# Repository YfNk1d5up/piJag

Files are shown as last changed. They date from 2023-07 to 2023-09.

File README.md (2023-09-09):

# piJag

Audio/Video Screen Unit of Jaguar X Type X400 based on a raspberry and openAuto pro: bluetooth, CarPlay, OBD, remote start, climate module control

[github] https://github.com/YfNk1d5up/piJag

## Hardware & Software

 - This project was initially thought for Jaguar X-Type X400 (2001) but some parts will work for other cars
 - It uses :
    - [Rpi 4B 4GB RAM](https://www.raspberrypi.com/products/raspberry-pi-4-model-b/)
    - [OpenAuto Pro](https://bluewavestudio.io/shop/openauto-pro-car-head-unit-solution/)
    - [CarPiHat](https://thepihut.com/products/carpihat-car-interface-hat-for-raspberry-pi)
    - [10.1" TouchScreen](https://www.amazon.fr/gp/product/B0B4VMNB42/ref=ppx_yo_dt_b_search_asin_image?ie=UTF8&psc=1)
    - [Carlinkit](https://www.amazon.fr/gp/product/B09ZQF182F/ref=ppx_yo_dt_b_asin_title_o05_s00?ie=UTF8&psc=1)
    - [USB Sound Card](https://www.amazon.fr/gp/product/B00IRVQ0F8/ref=ppx_yo_dt_b_asin_title_o04_s00?ie=UTF8&psc=1)
    - [Rear Camera](https://www.amazon.fr/gp/product/B0BG5M8H76/ref=ppx_yo_dt_b_asin_title_o01_s01?ie=UTF8&psc=1)
    - [CVBS to USB adapter](https://www.amazon.fr/gp/product/B0BYJ2892S/ref=ppx_yo_dt_b_asin_title_o01_s00?ie=UTF8&psc=1)
    - [12V Voltage Regulator](https://www.amazon.fr/gp/product/B09Q1XXM6G/ref=ppx_yo_dt_b_asin_title_o02_s00?ie=UTF8&psc=1)
    - [Powered USB Hub](https://www.amazon.fr/gp/product/B0BDFG1WZ7/ref=ppx_yo_dt_b_asin_title_o06_s00?ie=UTF8&psc=1)
    - [ELM327 OBD USB](https://www.amazon.fr/gp/product/B07NSPLVYW/ref=ppx_yo_dt_b_asin_title_o07_s00?ie=UTF8&psc=1)
    - 12V relays, Fan, Microphone, 4Channel Amplificator, HDMI & RCA cables, Audio Splitter ...
 - A custom PCB to control the Climate Control Module with an arduino nano (Kicad & JLCPCB)

## Features

- **Phone** : CarPlay, Android Auto, bluetooth, messages and calls
- **Rear Camera** : Automatic on reverse gear or anytime manually
- **Videos** : Kodi & Youtube
- **OBD** : CAN & SCP (Ford Protocol) messages and control
- **Climate** : Climate Control Module App
- **Mobile App** : Start the car, turn on heater or climatisation from Phone

## Screenshots

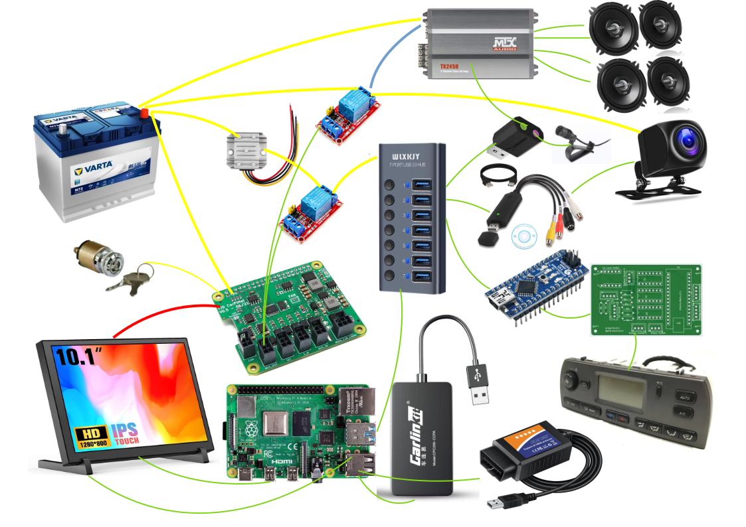
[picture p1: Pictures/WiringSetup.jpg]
Wiring Setup


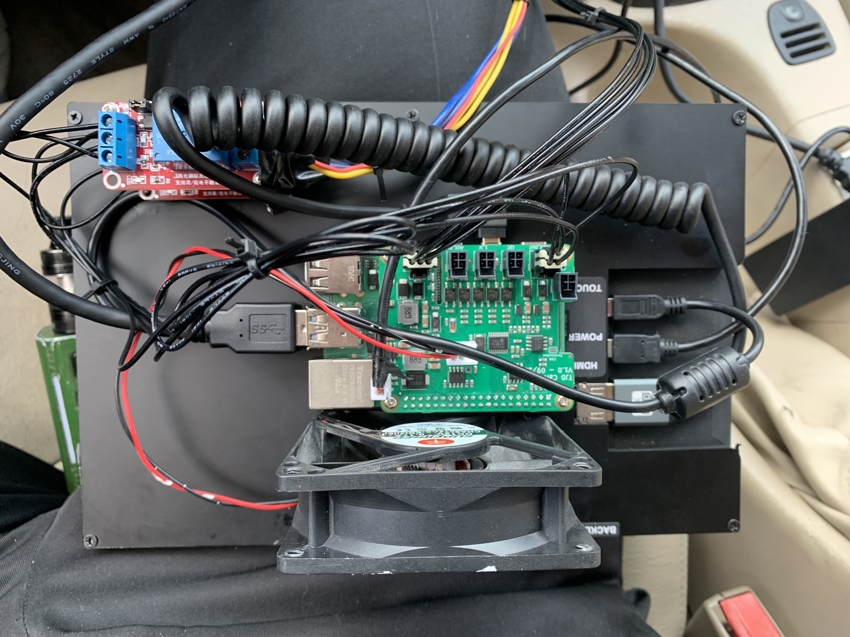
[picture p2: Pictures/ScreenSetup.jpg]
Screen Setup


Setup not clean for now (you can see the Climate Control Module annoying me for now, explaination later)...
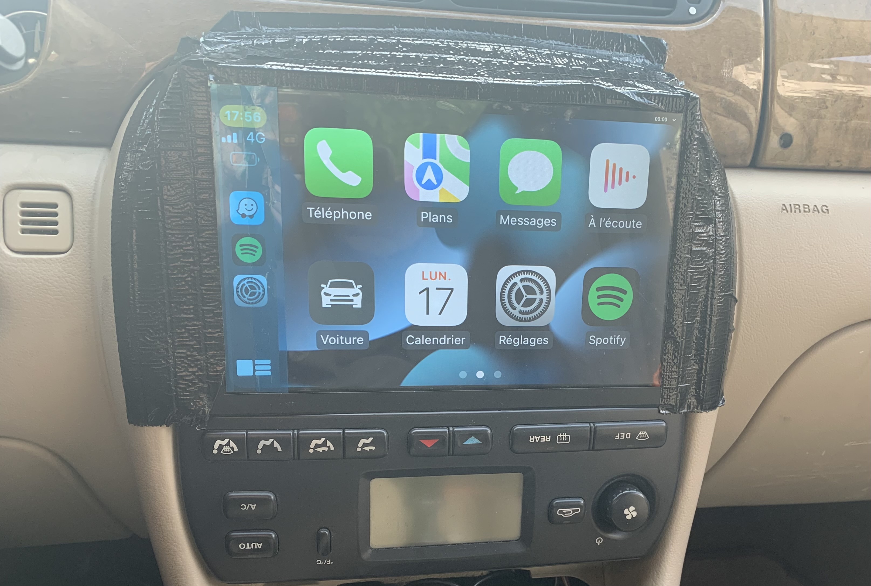
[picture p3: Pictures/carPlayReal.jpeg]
OpenAuto Pro CarPlay

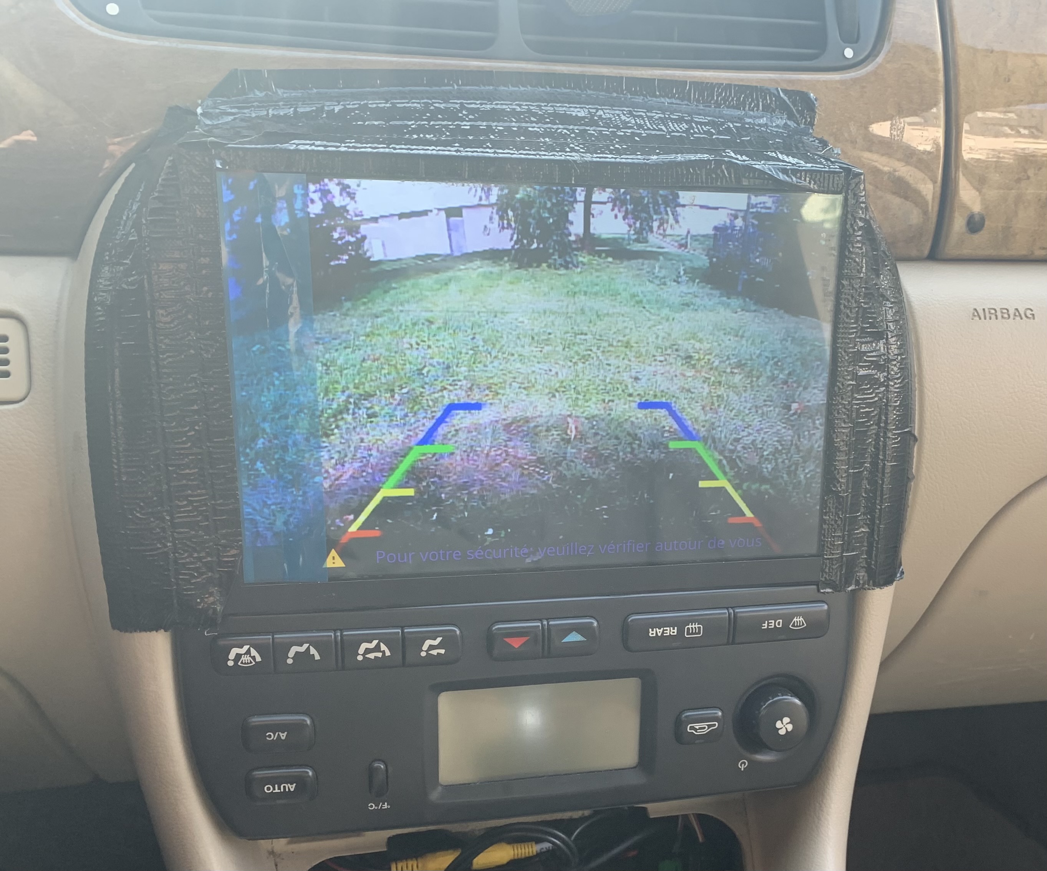
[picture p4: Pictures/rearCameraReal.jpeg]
OpenAuto Pro Rear Camera

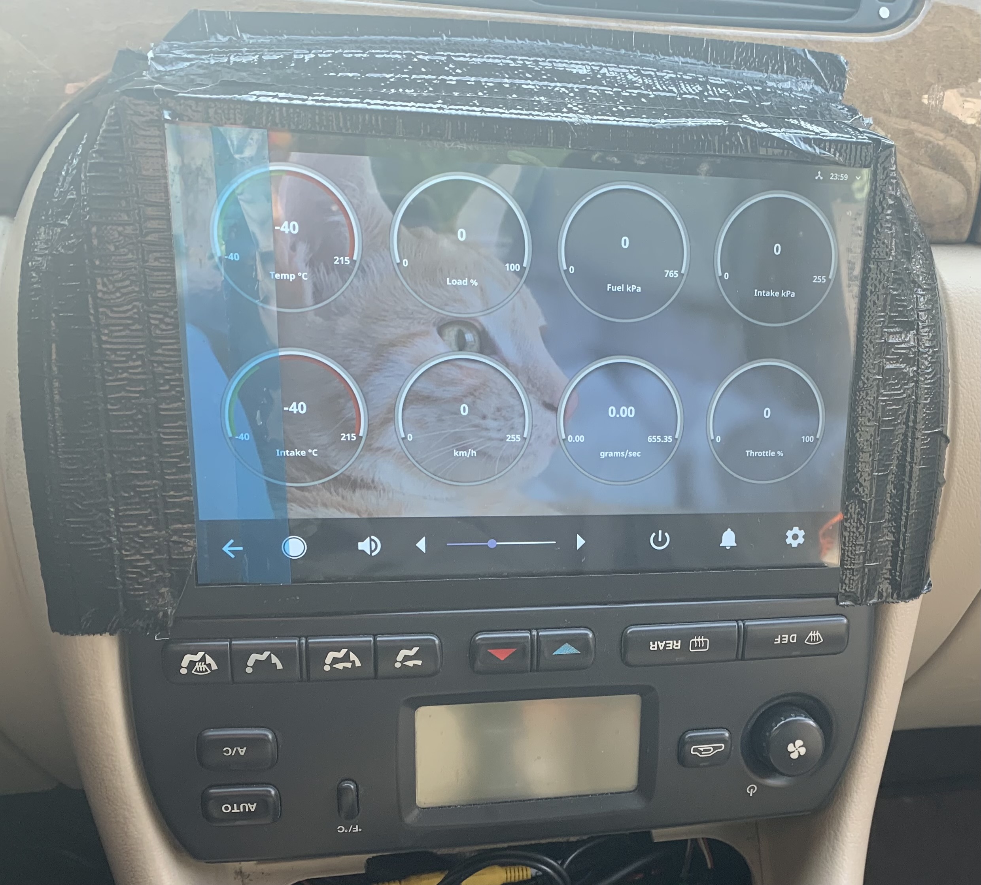
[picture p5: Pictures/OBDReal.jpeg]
OpenAuto Pro OBD

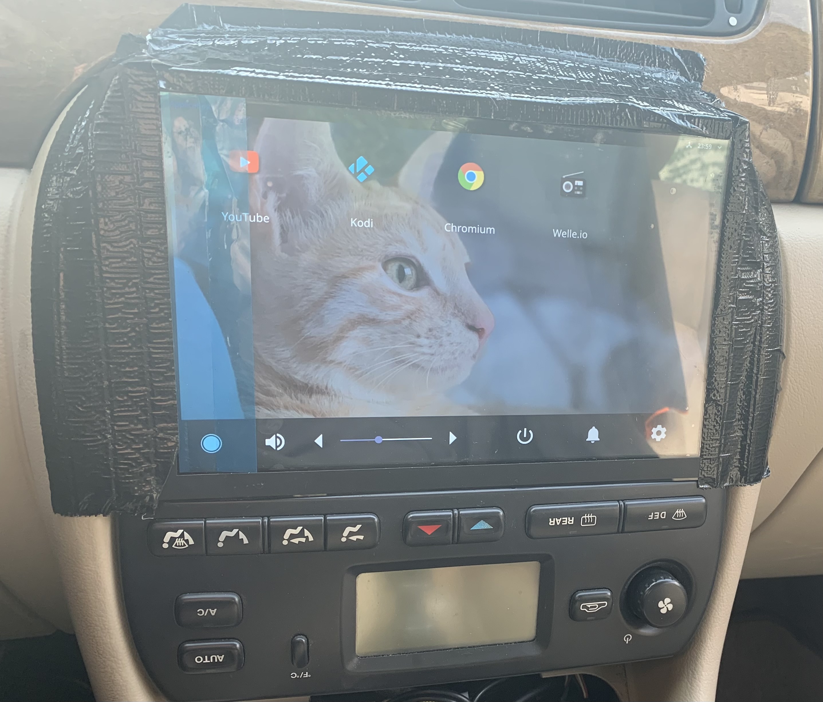
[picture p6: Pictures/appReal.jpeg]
OpenAuto Pro Apps


## Integration

### Raspberry Pi and carPiHat

The issue with installing custom hardware on a car is mainly how to power and connect them. Should I use the permanent 12V, switched 12V on key, interior lights 12V ...
The raspberry pi 4B is a 5V small computer that can draw 3A when loads are connected to it.
In this setup, a lot of usb devices are connected and I should consider this ~3A as a constant.
5V 3A, drawn from the car battery makes it impossible keeping powered on the constant battery supply.
In deed it needs to be powered off when I'm not in the car, and it needs a 12V to 5V step-down.
This is where I found [carPiHat](https://github.com/gecko242/CarPiHat) from TJD that saved me a lot of work :
- 12V - 5V buck converter to power the pi and touchscreen, with fuse and filtering.
- Safe shutdown circuitry to allow the pi to control its own power.
-  < 1mA current draw when switched off.
- Dedicated reverse, illumination and aux inputs, all opto isolated.
- 2 opto isolated general purpose inputs. (for a total of 5 inputs)
- 2 high current, high side switched 12V outputs (@1A). (for switching relays, lights ect)
- 1 independent CAN bus port.
- Real time clock to maintain system time across reboots.
- Broken out I2C bus.
- Broken out 1W for temperature sensor ect.
- 5V Power Output for display ect.

So the power aspect is done using this hat for the raspberry, connecting constant 12V, switched 12V, reverse gear input, illumination input, and GND

Then, a script makes the automation of the RPi power off 30s after turning the car off :

```python
import RPi.GPIO as GPIO # import our GPIO module
import time
from subprocess import call

GPIO.setmode(GPIO.BCM) # we are using BCM pin numbering

IGN_PIN = 12		# our 12V switched pin is BCM12
EN_POWER_PIN = 25	# our latch pin is BCM25

ILL_PIN = 13		# our 12V Illumination input pin is BCM13
REVERSE_PIN = 7	# our 12V Reverse Gear input pin is BCM7

IGN_LOW_TIME = 30 # time (s) before a shutdown is initiated after power loss

GPIO.setup(IGN_PIN, GPIO.IN) # set our 12V switched pin as an input
GPIO.setup(ILL_PIN, GPIO.IN) # same for ill and reverse 
GPIO.setup(REVERSE_PIN, GPIO.IN)

GPIO.setup(EN_POWER_PIN, GPIO.OUT, initial=GPIO.HIGH) # set our latch as an output

GPIO.output(EN_POWER_PIN, 1) # latch our power. We are now in charge of switching power off

ignLowCounter = 0

while 1:
	if GPIO.input(IGN_PIN) != 1: 				# if our 12V switched is not disabled
		time.sleep(1)							# wait a second
		ignLowCounter += 1						# increment our counter
		if ignLowCounter > IGN_LOW_TIME:		# if it has been switched off for >10s
			print("Shutting Down")
			call("sudo shutdown -h now", shell=True)	# tell the Pi to shut down
	else:
		ignLowCounter = 0 						# reset our counter, 12V switched is HIGH again

        time.sleep(0.1)  # Add a small sleep delay to reduce CPU usage
```

As said in TJD documentation in the *Opto-Isolated Inputs* section, I needed to redirect the CS1 pin to BCM24 to get ill and reverse inputs to work.

From the hat I also used the 2 outputs to control relays :
- One relay powers the **4Channels Audio Amplifier remote** and the rear camera with 12V
- The other powers the **36W USB Hub** to relieve the strain on the raspberry and charge devices.

(picture)

#### **Parts to come with carPiHat** :
- CAN integration
- I/O expander to add remote powering the car and other stuff

### TouchScreen 

Simply an HDMI and touch USB connected to the RPi, plus 5V power coming from the carPiHat

### Suffering from Hot Temperatures

During summer 2023, a lot of heat has made the setup suffer. This is where I add a 12V computer power fan to help keeping the whole setup at acceptable temperatures.

## obdSniffer

To add more control on the car, I tried to hack bus networks through the OBD2 port.

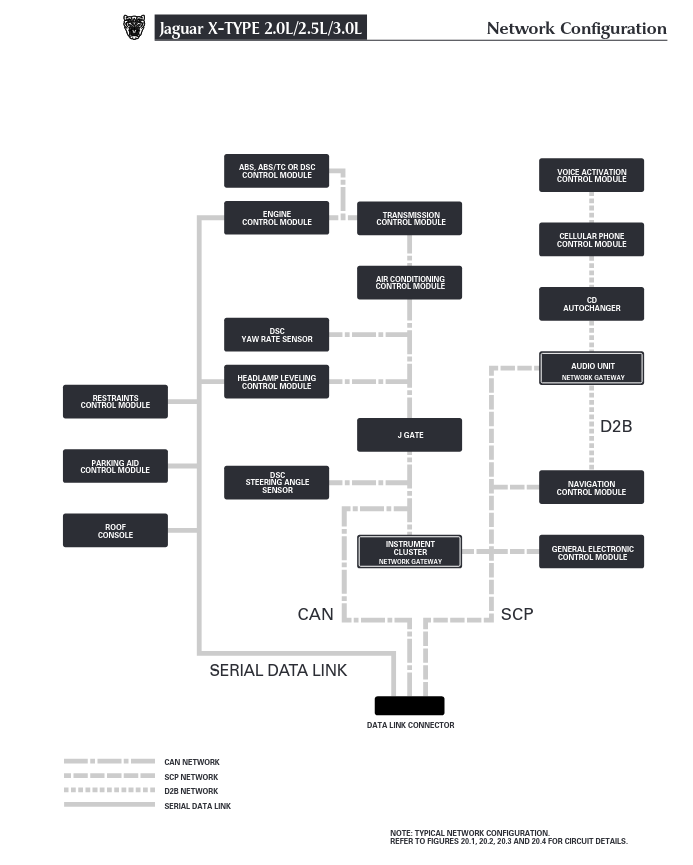
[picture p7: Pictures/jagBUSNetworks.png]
X-Type BUS Networks


### CAN Bus

Following this awesome serie from Youtube [How to hack your car ](https://youtu.be/cAAzXM5vsi0) by Adam Varga and using his python&Qt [CAN_Gui](https://github.com/adamtheone/canDrive), I copy the setup to hack into my CAN Bus.

Here are for example some data I decoded : 

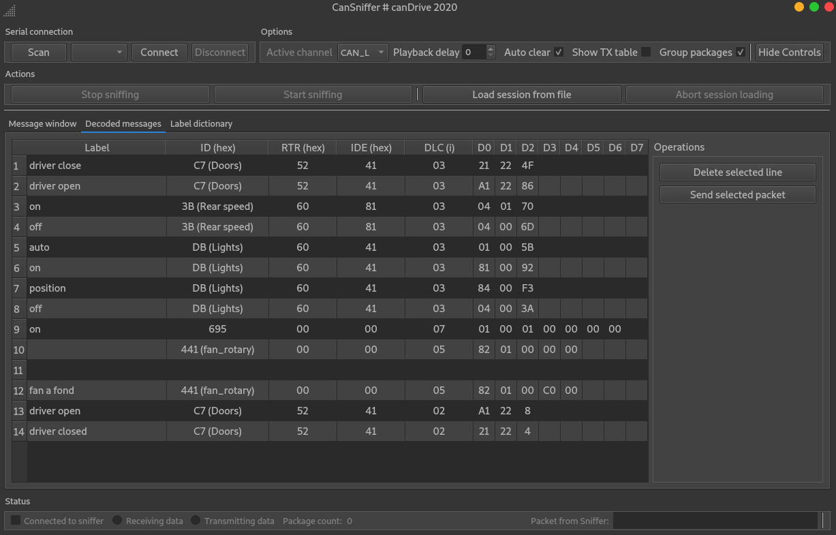
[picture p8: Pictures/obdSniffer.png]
obdSniffer GUI


### SCP Bus

As the X-Type shares its creation with the Ford Mondeo, the car uses SAEJ1850 PWM aka **Standard Corporate Protocol** or **SCP** to communicate low priority information between modules.

A modification of Adam Varga code brings me the SCP decoding using the **ELM327 OBD2 USB Reader** using **AT** commands.
Modified functions :
*serialPacketReceiverCallback*
*serialPortConnect*
file *SerialReader.py*

(You can see some SCP data on the previous screenshot)

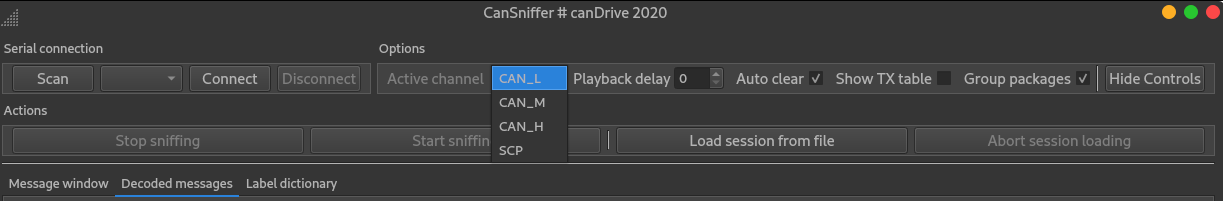
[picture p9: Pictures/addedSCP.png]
SCP Added


To achieve that, first I did some tests using AT on linux terminal

```bash
sudo screen /dev/ttyUSB0 38400
```

```bash
>atz
ELM327 v1.5

>atl1
OK

>ath1
OK

>ats1
OK

>atal
OK

>atsp1
OK

>atma

```

For AT commands explanation, SCP application case and another hardware setup, see this thread : https://www.jaguarforum.com/threads/reverse-engineering-hacking-scp-bus-to-xj-x350-x358-s-type-and-x-type.108639/

Example output :

```bash
81 29 60 02 0081 29 60 02 00 00 11
41 87 60 04 08 B1
81 7B 60 02 00 4C
81 7B 60 02 00 4C
```

See [X-Type Electrical Guide CAN/SCP](https://github.com/YfNk1d5up/piJag/blob/cf38571dc9505988becb3cf82d76548922db3a51/Docs/JagClimModule.pdf) to find more information about CAN and SCP messages

## OpenAuto Pro setup

## Climate Control Module Hack

The goal here was to remove the Control Unit that is space-consuming and overall avoid me to install the screen properly without destroying the case.
To continue adding a modern touch to my X-Type, I enjoy controlling the climate directly on the touchscreen via an app on openAuto Pro.

Firstly, I need to understand well how the existing module works.
So I bought another one to avoid getting stuck breaking it : in deed, it is connected to the CAN Bus and the car will not start if the module doesn't work or isn't connected to the bus.

By the CAN and SCP analyse done previously, I found that buttons user actions are not going through any bus on the car, plus the electrical documentation shows that the module only communicate with other modules to say an action has been performed.
FYI, the second X-Type (X404) added LIN to the buses, where climate, windows control, driver wheel buttons, etc, communicate through it.

But no chance, that is not the case for my version. So sending commands on buses to control the climate module is impossible.

That said, there is no other way than hacking electronics of the module by adding a custom Mod PCB.

The Module consists in 2 PCBs connected by a 20 wires ribbon. On the electrical documentation, only the global module connections to the rest of the car is detailed. 
Lucky for me, somebody already took a look into that module, because he wanted to change the screen to a modern one. The report is joined in [David's initial HVAC Sniffer](https://github.com/YfNk1d5up/piJag/blob/cf38571dc9505988becb3cf82d76548922db3a51/Docs/p10018_jag_hvac_sniffer.zip)

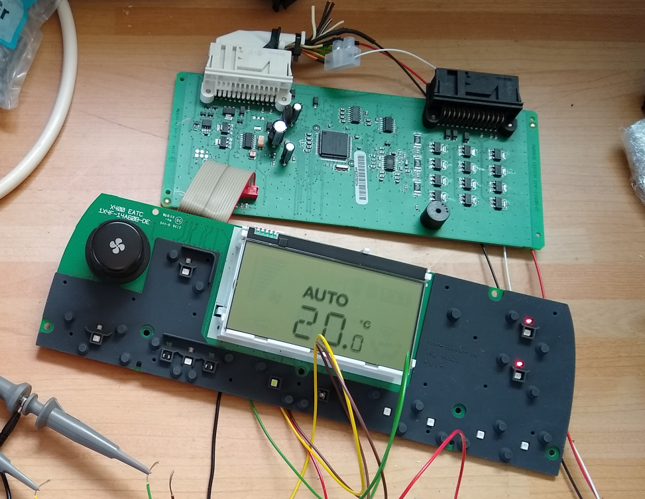
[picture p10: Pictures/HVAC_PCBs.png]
(HVAC PCBs)


The first PCB contains the MCU which does CAN communication to the rest of the vehicule, control of fans, compressor, etc : that is the one I want to keep.
The second one contains all the buttons, the LCD screen, a digital encoder, and maybe a second propietary MCU impossible to identify : I want to replace this PCB.
Doing some retro-engineering and finding the documentation of the MCU in the first PCB, here is the connection from and to that second PCB :

[Initial retro-engineering of the 2nd PCB](https://github.com/YfNk1d5up/piJag/blob/cf38571dc9505988becb3cf82d76548922db3a51/Docs/piJagClim_existing_module.pdf)

You can see here a switches matrix, using 6 wires for 12 buttons. An I2C screen connected straigth to the main MCU, a rotary encoder also directly connected to the main board.
What I used for the buttons is analog switches, that works as relays except that they are small 14 pins chips, which each entry is controlled by an Arduino digital pin. For the rotary encoder, an Arduino Nano can easily simulate the signals by using two digital pins.
Finally, using David's work about the i2c screen, I can get the information coming from the main MCU by decoding it using A4 and A5 pins on the Nano.

And so here is the mod board :
climateModBoardv0.2
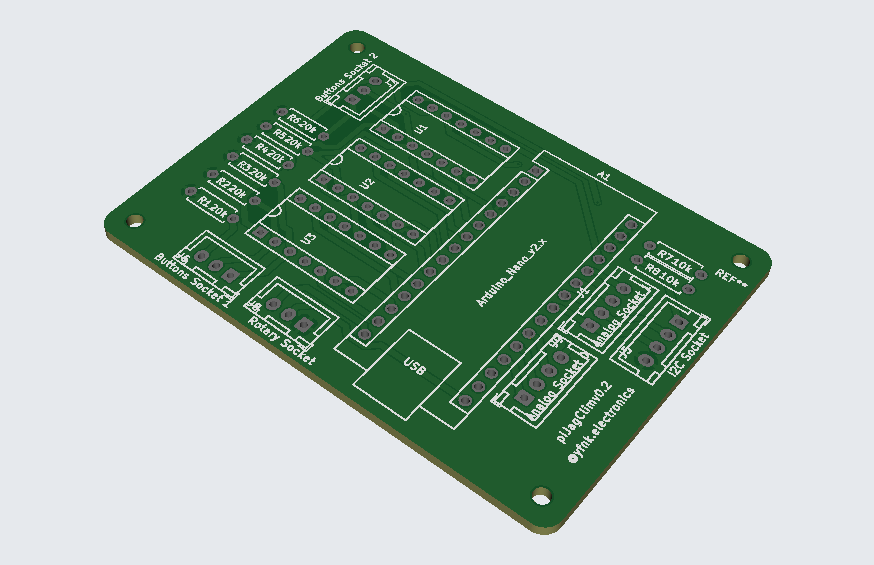
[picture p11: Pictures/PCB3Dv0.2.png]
PCB3Dv0.2


JLCPCB Manufacture :

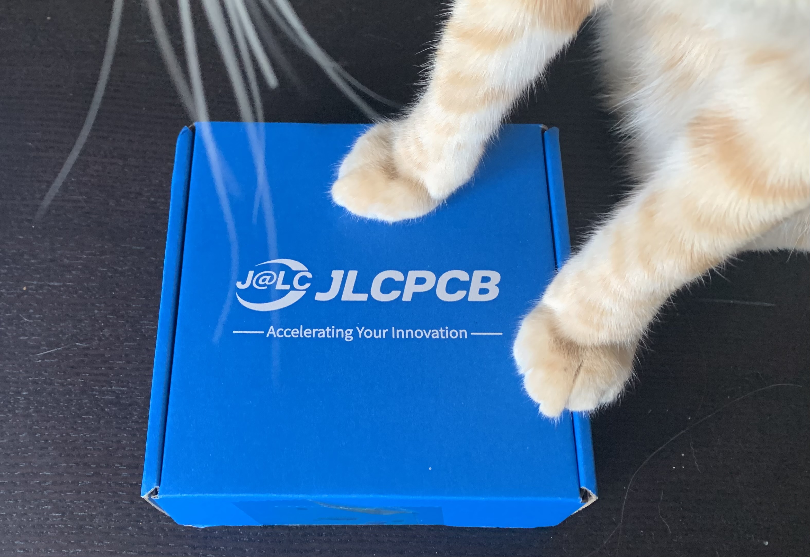
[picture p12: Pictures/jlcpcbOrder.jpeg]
JLCPCB Order

![PCB not mounted]
![PCB mounted]

To communicate with the arduino onboard, a pyQt App controls the mod, associated with an arduino code that simulates the action and transmit the i2c data.

[pyQtApp](Software/piJagClimApp)
[piJagClimI2C.ino](Hardware/piJagClim/newPCB/arduino/piJagClimI2C/piJagClimI2C.ino)

Here you can see the Qt App v0.1 :
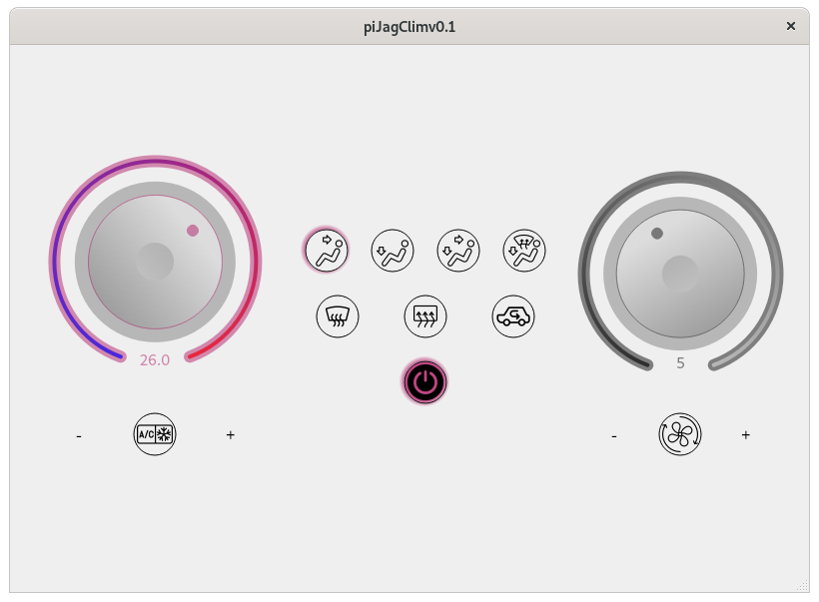
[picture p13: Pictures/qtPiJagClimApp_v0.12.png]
piJagClimAppv0.1


## Ressources

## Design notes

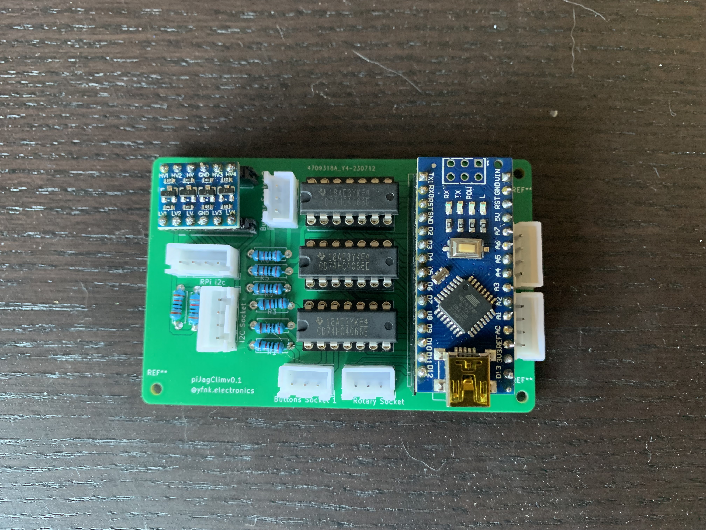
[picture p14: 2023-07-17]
Pictures/PCBmounted.jpeg

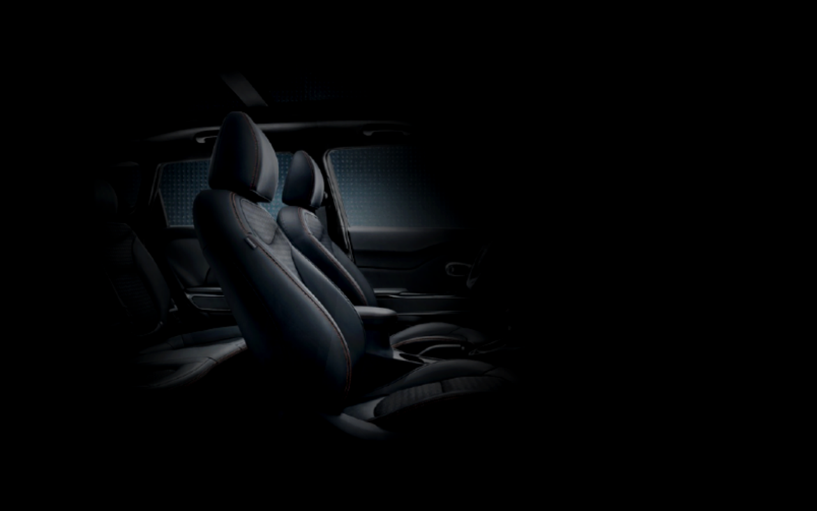
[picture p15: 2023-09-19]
Software/piJagClimApp/v0.2/pictures/background.png

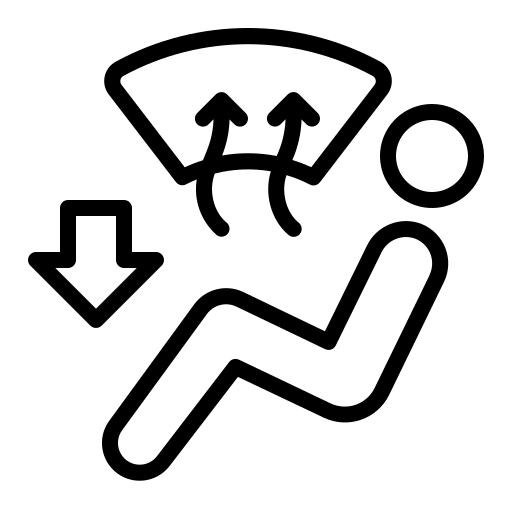
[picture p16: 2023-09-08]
Software/piJagClimApp/v0.2/pictures/feetfront.png

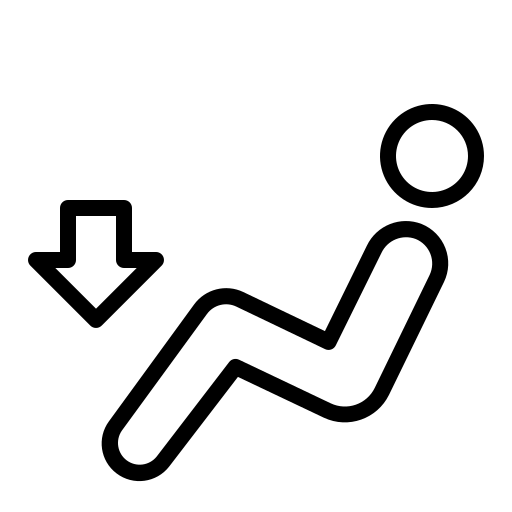
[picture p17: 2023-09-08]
Software/piJagClimApp/v0.2/pictures/feet.png

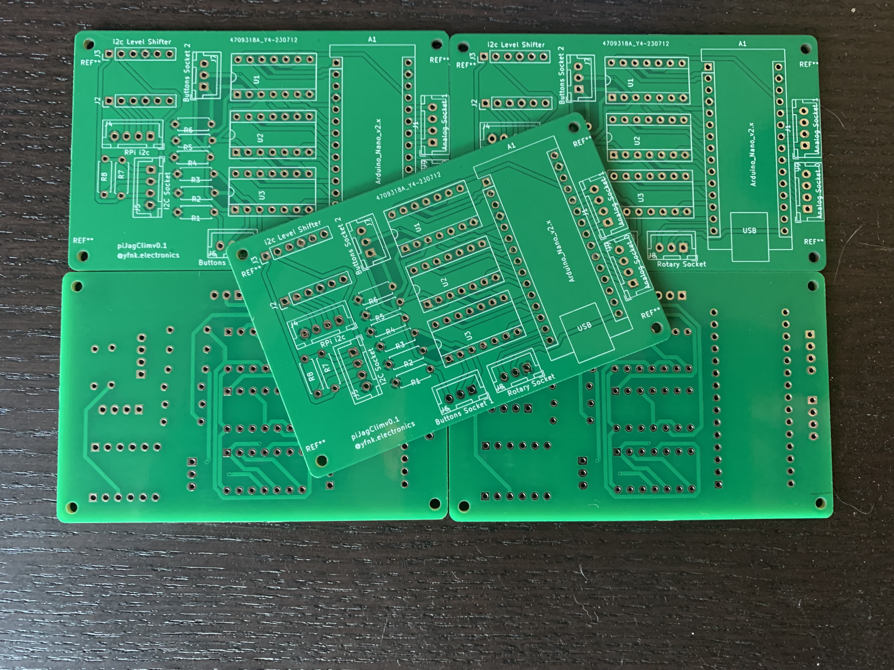
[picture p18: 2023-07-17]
Pictures/PCBnotmounted.jpeg

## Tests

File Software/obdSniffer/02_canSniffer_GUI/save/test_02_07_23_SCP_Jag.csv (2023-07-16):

600.969 | FE | 60 | 41 | 01 | 82 | 5
601.801 | 89 | 52 | 41 | 01 | 50 | 0
601.657 | 39 | 52 | 41 | 02 | 82 | 01 | B
601.833 | 93 | 60 | 41 | 03 | 06 | 7F | 01 | D
640.298 | C7 (Doors) | 52 | 41 | 02 | 21 | 26 | 3
601.609 | 33 (Handbrake) | 60 | 41 | 01 | A0 | C
601.898 | 85 | 60 | 41 | 01 | 21 | 1
602.025 | 88 (Driver Belt) | 52 | 41 | 01 | 81 | 6
236.633 | 8D (Climate) | 60 | A1 | 07 | 01 | 00 | 00 | 00 | 00 | 00 | 00 | 9
601.866 | DB (Lights) | 60 | 41 | 02 | 04 | 00 | 3
743.545 | 3B (Rear speed) | 60 | 81 | 02 | 04 | 00 | 6
744.009 | 29 | 60 | 81 | 03 | 02 | 00 | 00 | 1
743.929 | 87 | 60 | 41 | 02 | 04 | 08 | B
744.073 | 7B | 60 | 81 | 02 | 02 | 00 | 4

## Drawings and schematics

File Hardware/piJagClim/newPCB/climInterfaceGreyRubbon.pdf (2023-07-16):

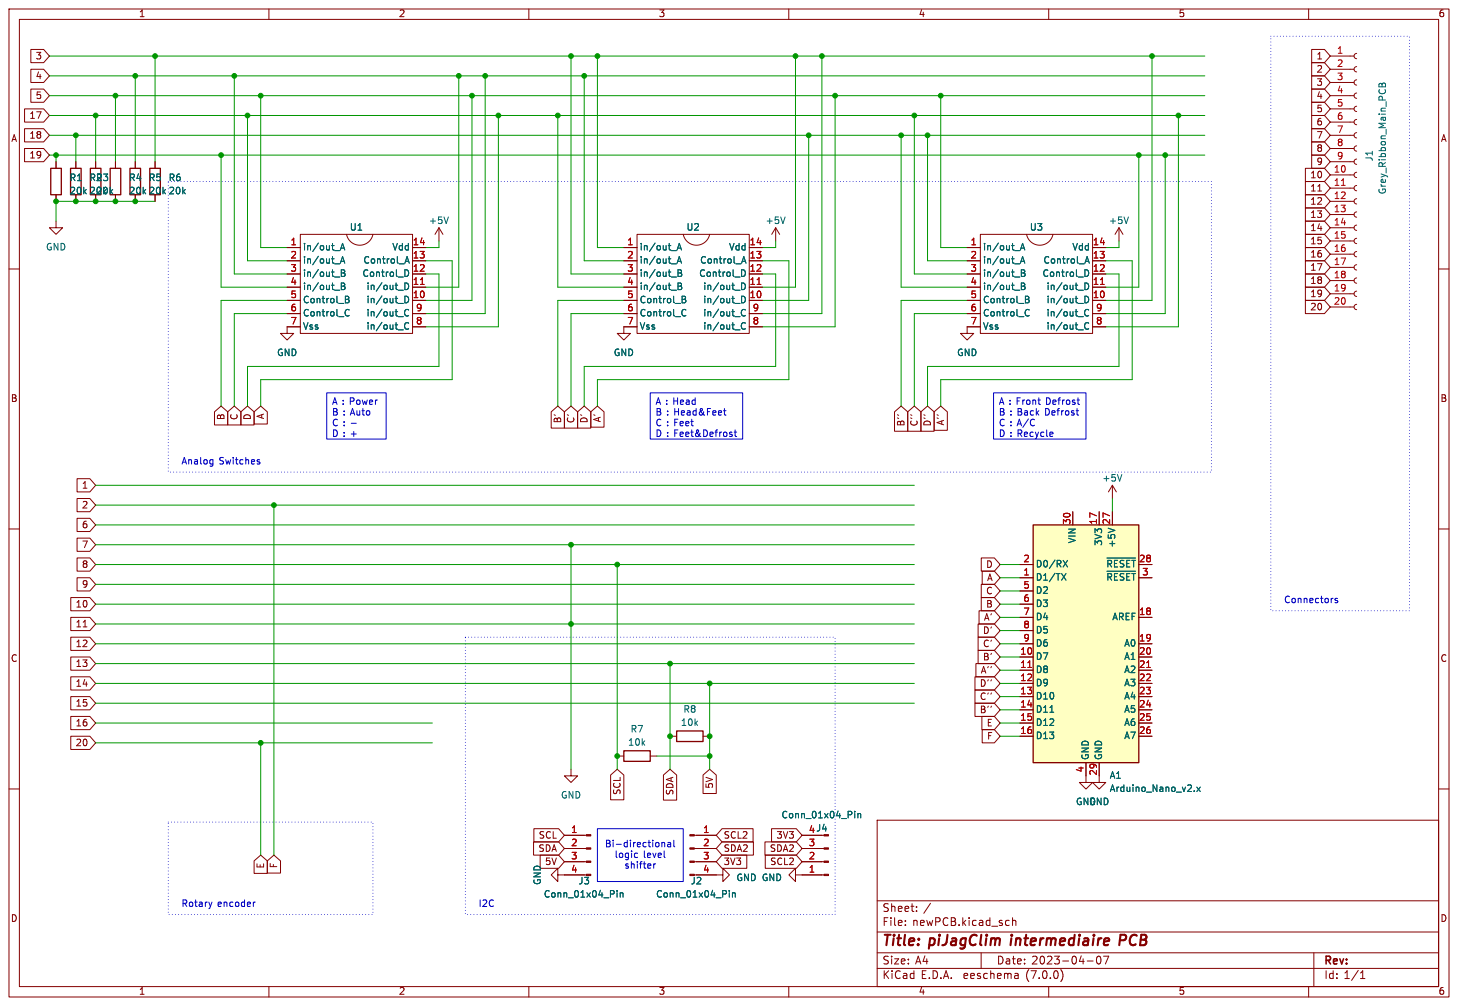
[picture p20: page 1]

File: newPCB.kicad_sch Sheet: /
Id: 1/1 Title: piJagClim intermediaire PCB

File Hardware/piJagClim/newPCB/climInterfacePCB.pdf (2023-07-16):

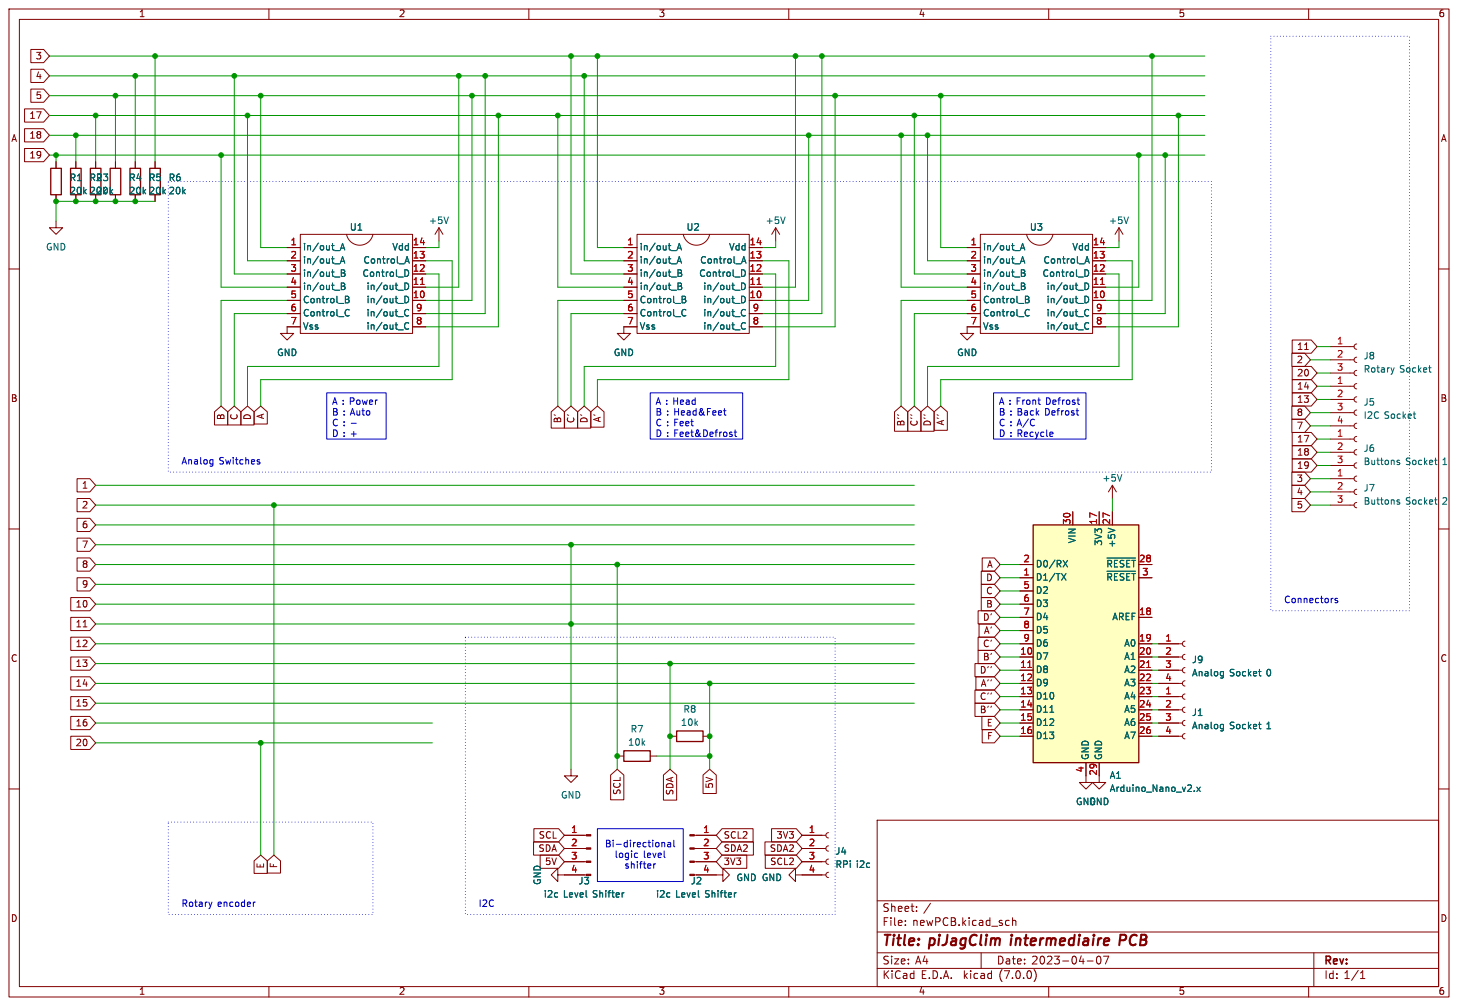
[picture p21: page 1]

File: newPCB.kicad_sch Sheet: /
Id: 1/1 Title: piJagClim intermediaire PCB

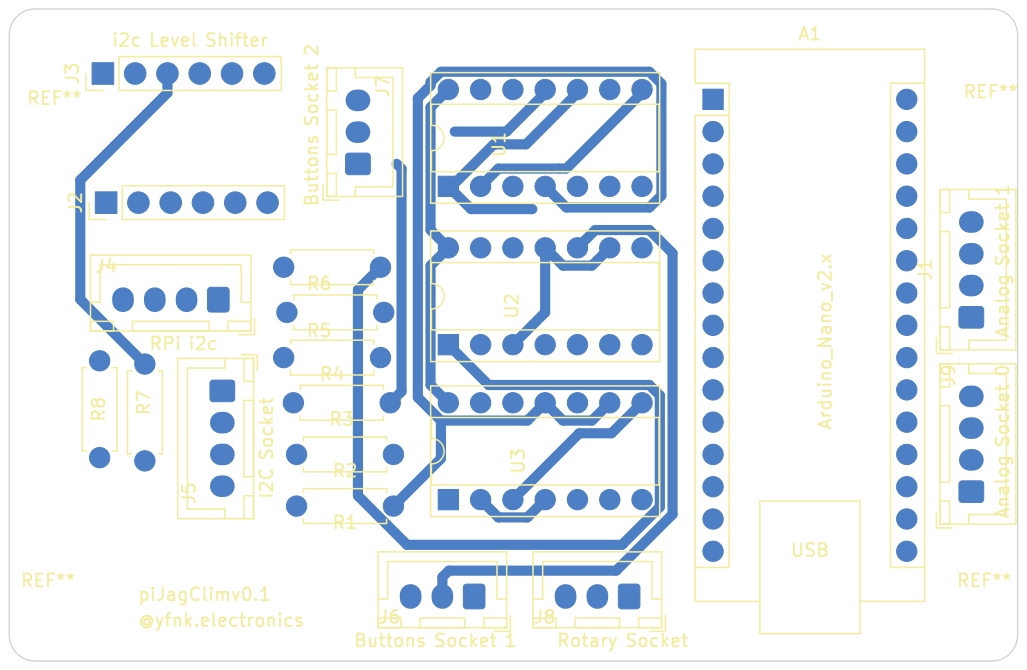
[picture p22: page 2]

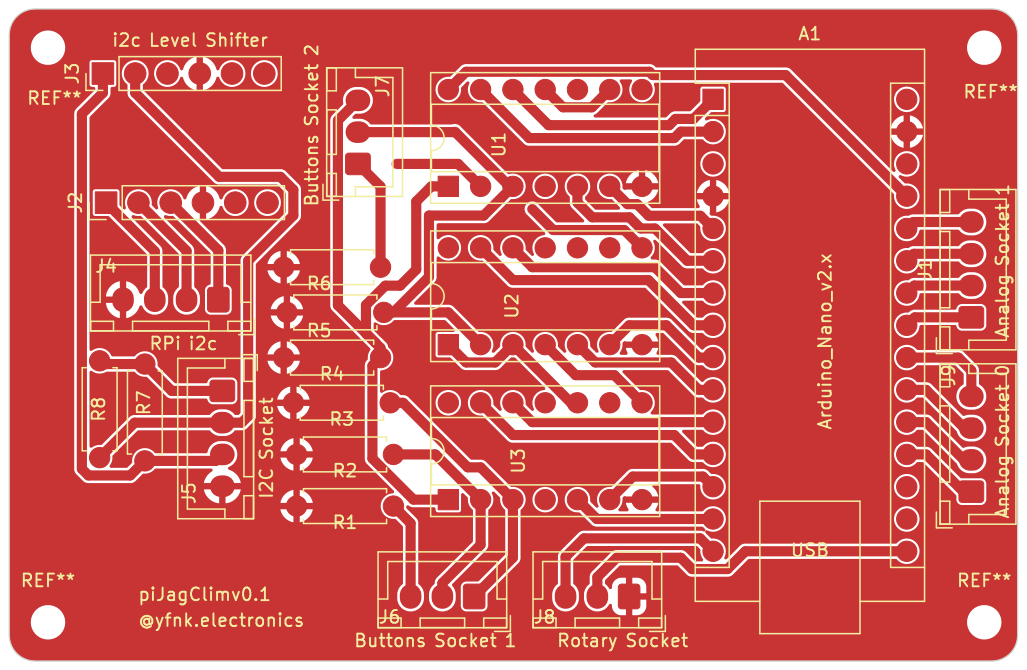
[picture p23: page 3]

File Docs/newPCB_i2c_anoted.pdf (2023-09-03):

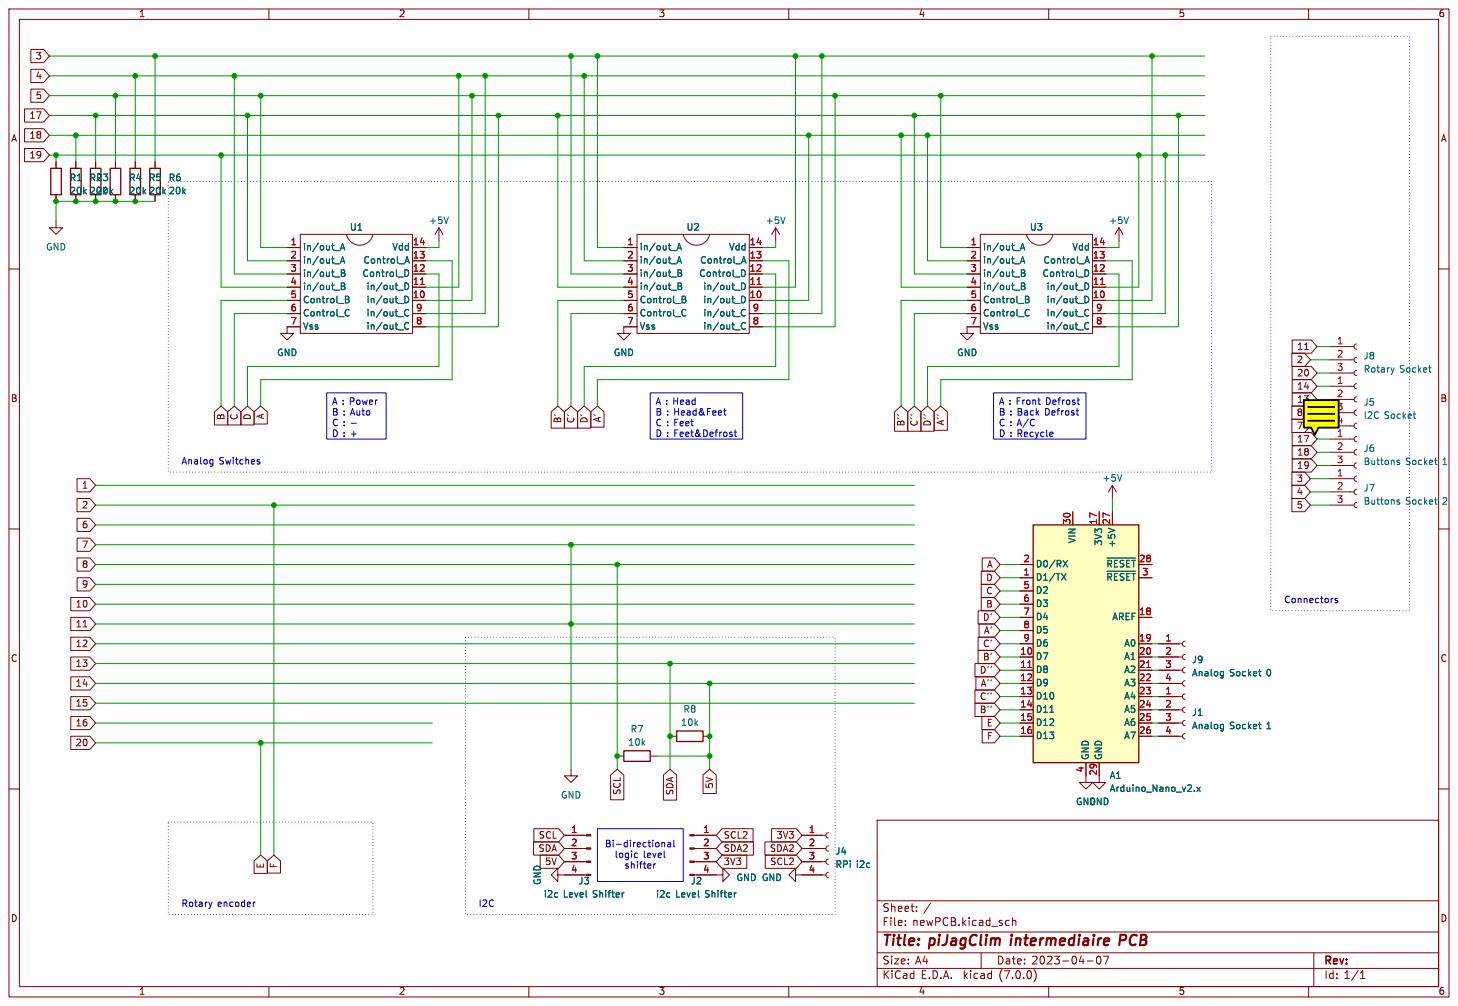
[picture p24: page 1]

File: newPCB.kicad_sch Sheet: /
Id: 1/1 Title: piJagClim intermediaire PCB

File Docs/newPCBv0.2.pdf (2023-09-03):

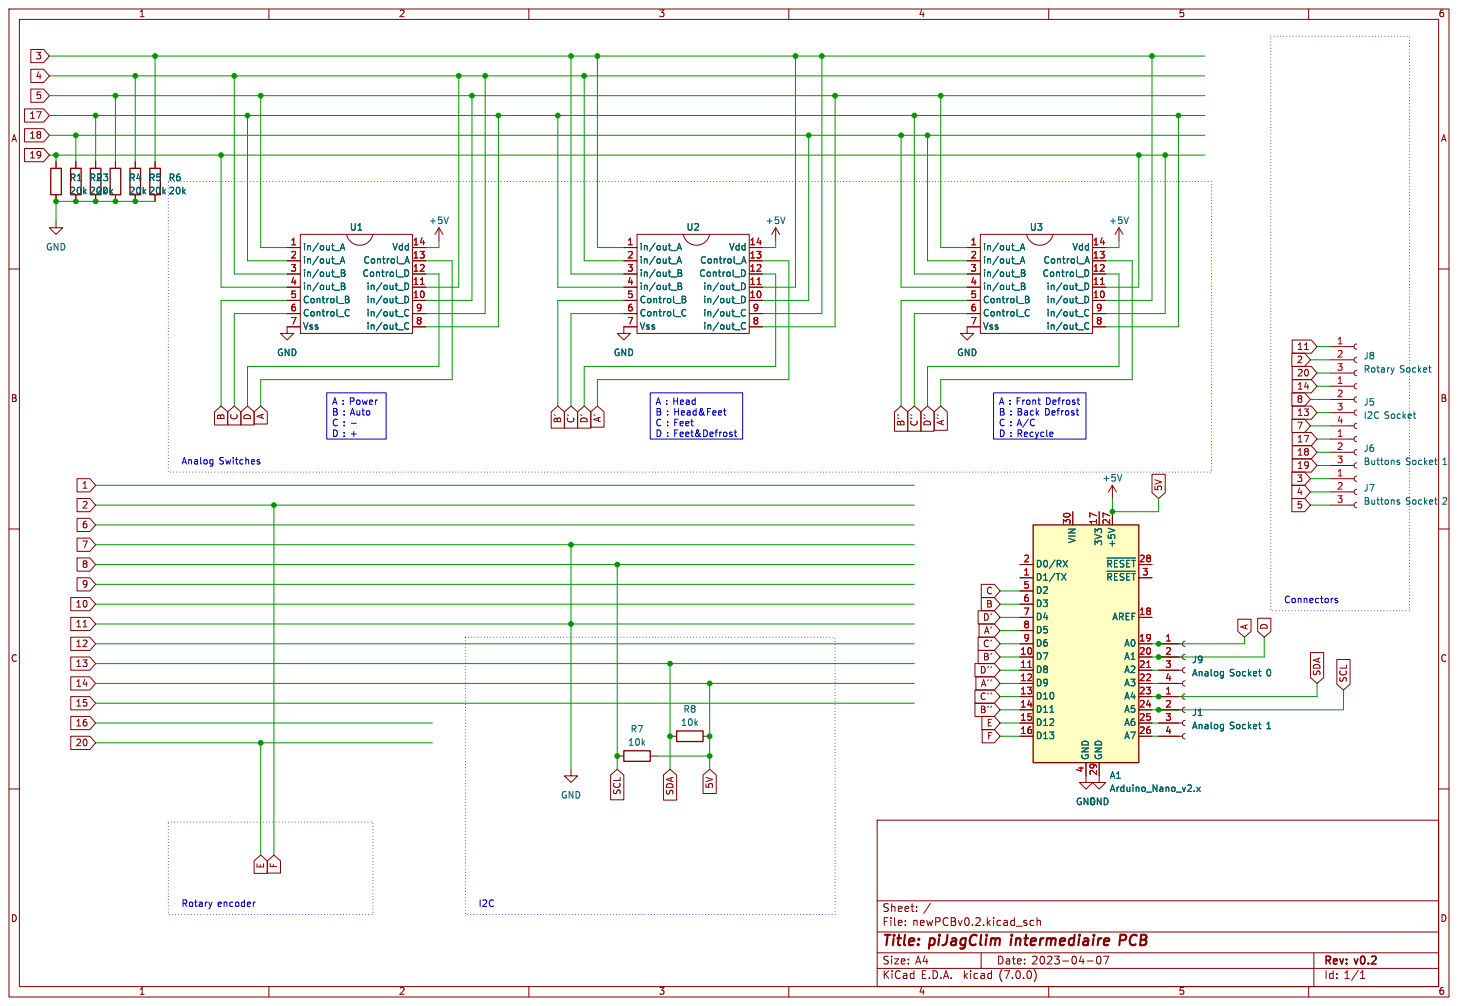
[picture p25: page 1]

File: newPCBv0.2.kicad_sch Sheet: /
Id: 1/1 Title: piJagClim intermediaire PCB

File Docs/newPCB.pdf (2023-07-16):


File: newPCB.kicad_sch Sheet: /
Id: 1/1 Title: piJagClim intermediaire PCB

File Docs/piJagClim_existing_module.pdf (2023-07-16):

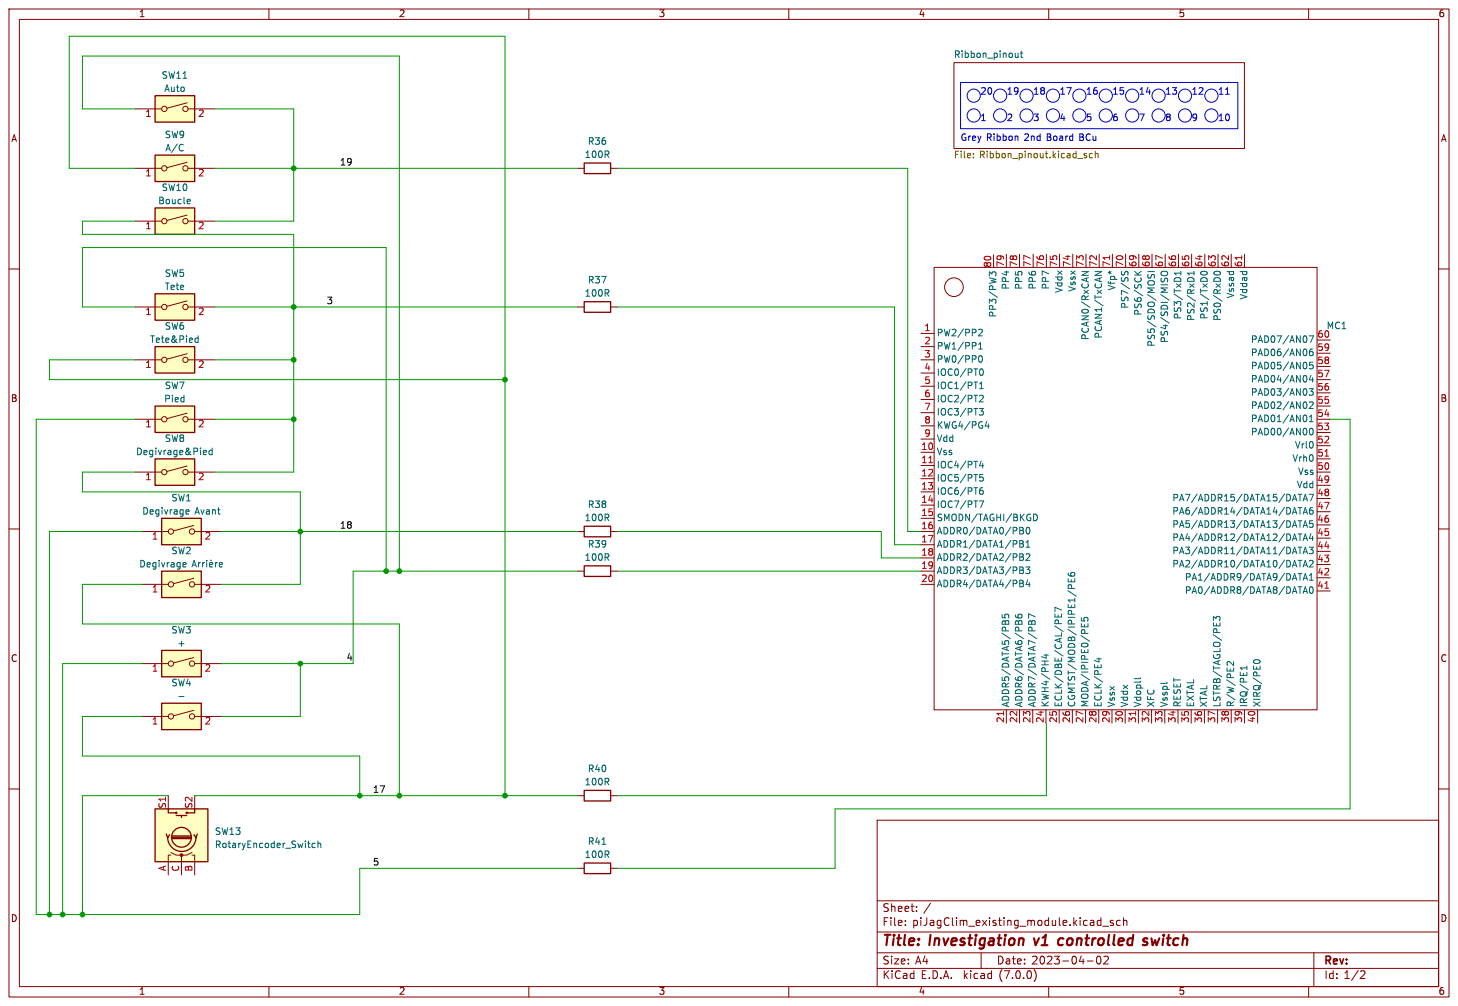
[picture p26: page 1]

File: piJagClim_existing_module.kicad_sch Sheet: /
Id: 1/2 Title: Investigation v1 controlled switch

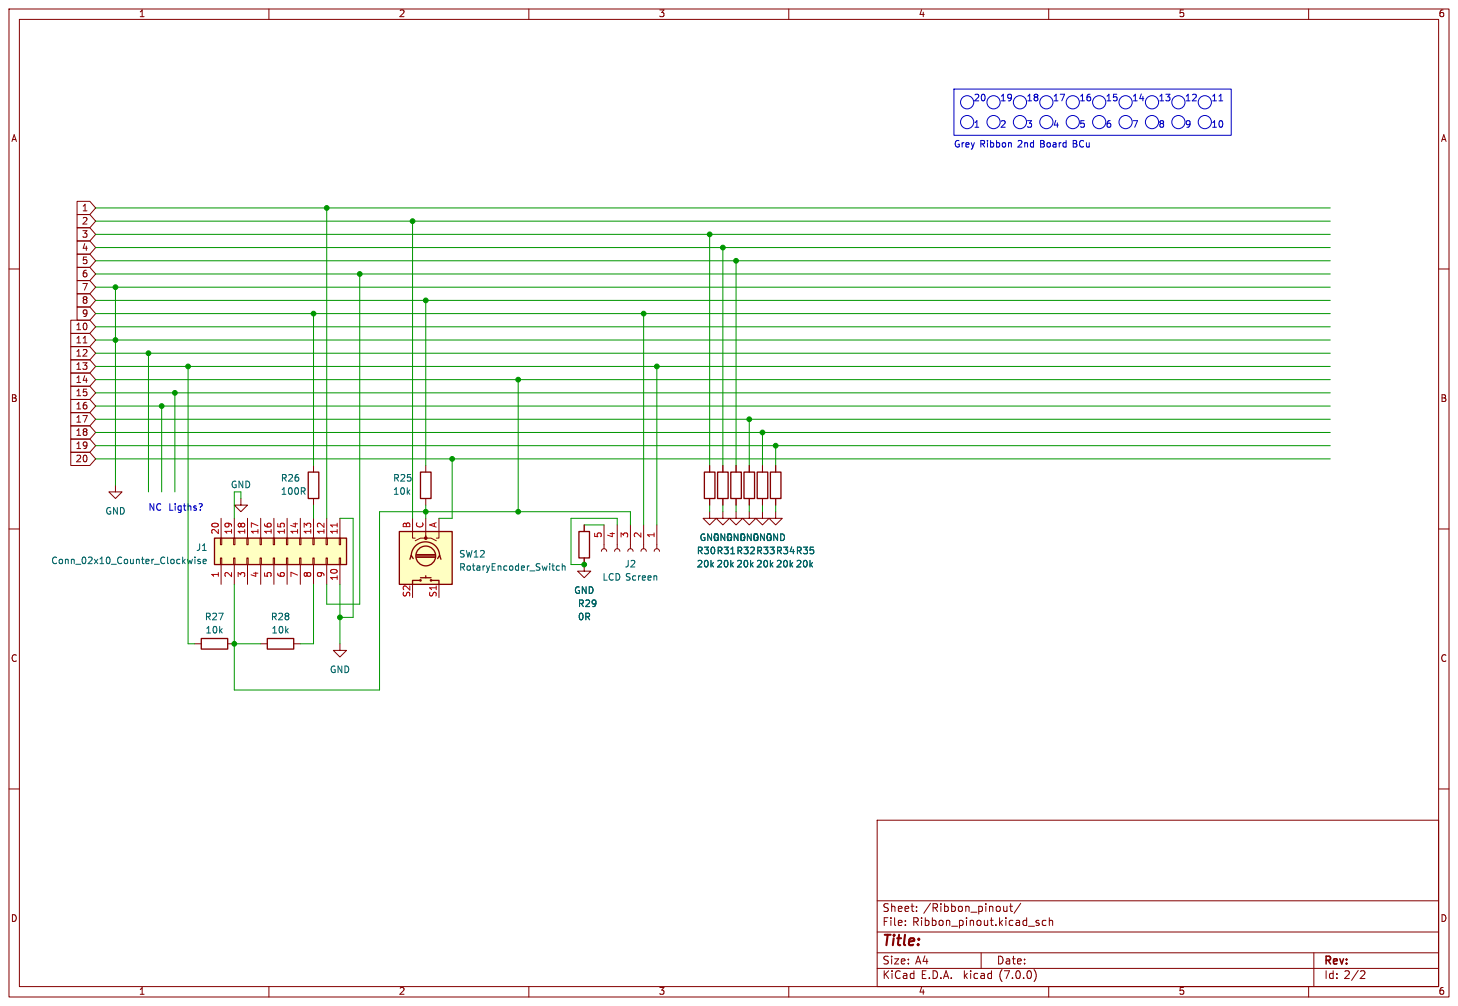
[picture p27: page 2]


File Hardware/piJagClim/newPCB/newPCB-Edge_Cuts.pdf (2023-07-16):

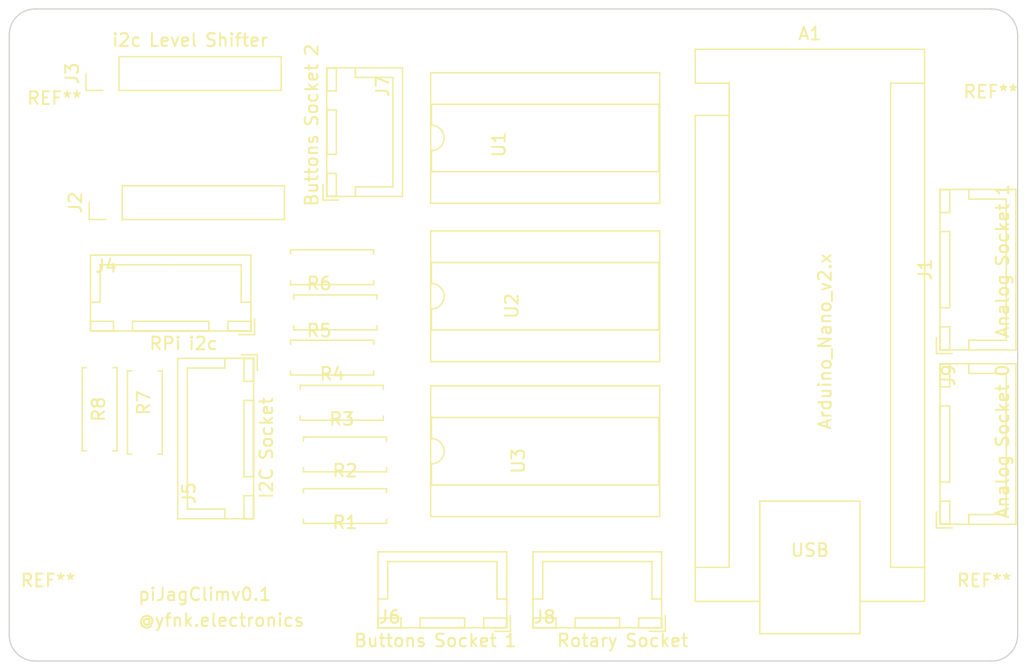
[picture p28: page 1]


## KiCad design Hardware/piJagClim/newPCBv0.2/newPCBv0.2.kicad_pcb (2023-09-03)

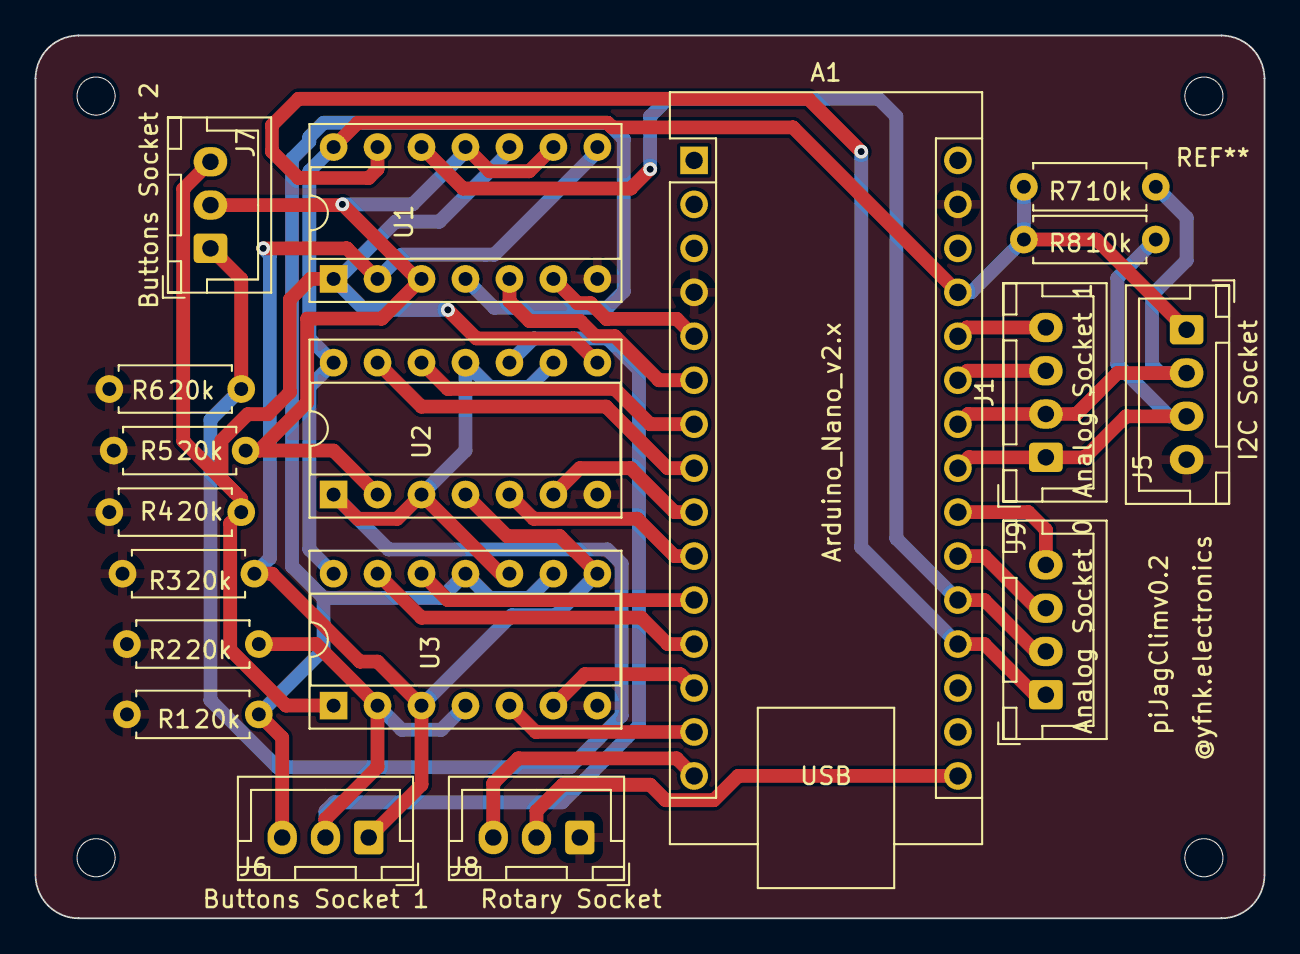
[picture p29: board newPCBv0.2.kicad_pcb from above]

Board: 2 copper layers, 71.0 x 51.0 mm, 18 parts (0 on the bottom side), 28 nets.

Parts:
A1: Arduino_Nano_v2.x; Arduino_Nano
J1: Analog Socket 1; JST_XH_B4B-XH-A_1x04_P2.50mm_Vertical
J5: I2C Socket; JST_XH_B4B-XH-A_1x04_P2.50mm_Vertical
J6: Buttons Socket 1; JST_XH_B3B-XH-A_1x03_P2.50mm_Vertical
J7: Buttons Socket 2; JST_XH_B3B-XH-A_1x03_P2.50mm_Vertical
J8: Rotary Socket; JST_XH_B3B-XH-A_1x03_P2.50mm_Vertical
J9: Analog Socket 0; JST_XH_B4B-XH-A_1x04_P2.50mm_Vertical
R1, R2, R3, R4, R5, R6: 20k; R_Axial_DIN0207_L6.3mm_D2.5mm_P7.62mm_Horizontal
R7, R8: 10k; R_Axial_DIN0207_L6.3mm_D2.5mm_P7.62mm_Horizontal
U1, U2, U3: DIP-14_W7.62mm_Socket

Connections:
2: A1.16 (D13), J8.2
3: J7.1, R6.1, U2.1 (in/out_A), U2.3 (in/out_B), U2.9 (in/out_C), U2.11 (in/out_D), U3.10 (in/out_D)
4: J7.2, R5.1, U1.3 (in/out_B), U1.9 (in/out_C), U1.11 (in/out_D), U2.2 (in/out_A)
5: J7.3, R4.1, U1.1 (in/out_A), U1.10 (in/out_D), U2.8 (in/out_C), U3.1 (in/out_A)
8: A1.24 (A5), J1.2, J5.2, R7.2
11: A1.4 (GND), A1.29 (GND), J5.4, J8.1, R1.2, R2.2, R3.2, R4.2, R5.2, R6.2, U1.7 (Vss), U2.7 (Vss), U3.7 (Vss)
13: A1.23 (A4), J1.1, J5.3, R8.2
14: A1.27 (+5V), J5.1, R7.1, R8.1, U1.14 (Vdd), U2.14 (Vdd), U3.14 (Vdd)
17: J6.1, R3.1, U1.2 (in/out_A), U1.8 (in/out_C), U2.4 (in/out_B), U3.3 (in/out_B), U3.8 (in/out_C)
18: J6.2, R2.1, U2.10 (in/out_D), U3.2 (in/out_A), U3.4 (in/out_B)
19: J6.3, R1.1, U1.4 (in/out_B), U3.9 (in/out_C), U3.11 (in/out_D)
20: A1.15 (D12), J8.3
A: A1.19 (A0), J9.1, U1.13 (Control_A)
A': A1.8 (D5), U2.13 (Control_A)
A'': A1.12 (D9), U3.13 (Control_A)
B: A1.6 (D3), U1.5 (Control_B)
B': A1.10 (D7), U2.5 (Control_B)
B'': A1.14 (D11), U3.5 (Control_B)
C: A1.5 (D2), U1.6 (Control_C)
C': A1.9 (D6), U2.6 (Control_C)
C'': A1.13 (D10), U3.6 (Control_C)
D: A1.20 (A1), J9.2, U1.12 (Control_D)
D': A1.7 (D4), U2.12 (Control_D)
D'': A1.11 (D8), U3.12 (Control_D)
unnamed: A1.21 (A2), J9.3
unnamed: A1.22 (A3), J9.4
unnamed: A1.25 (A6), J1.3
unnamed: A1.26 (A7), J1.4

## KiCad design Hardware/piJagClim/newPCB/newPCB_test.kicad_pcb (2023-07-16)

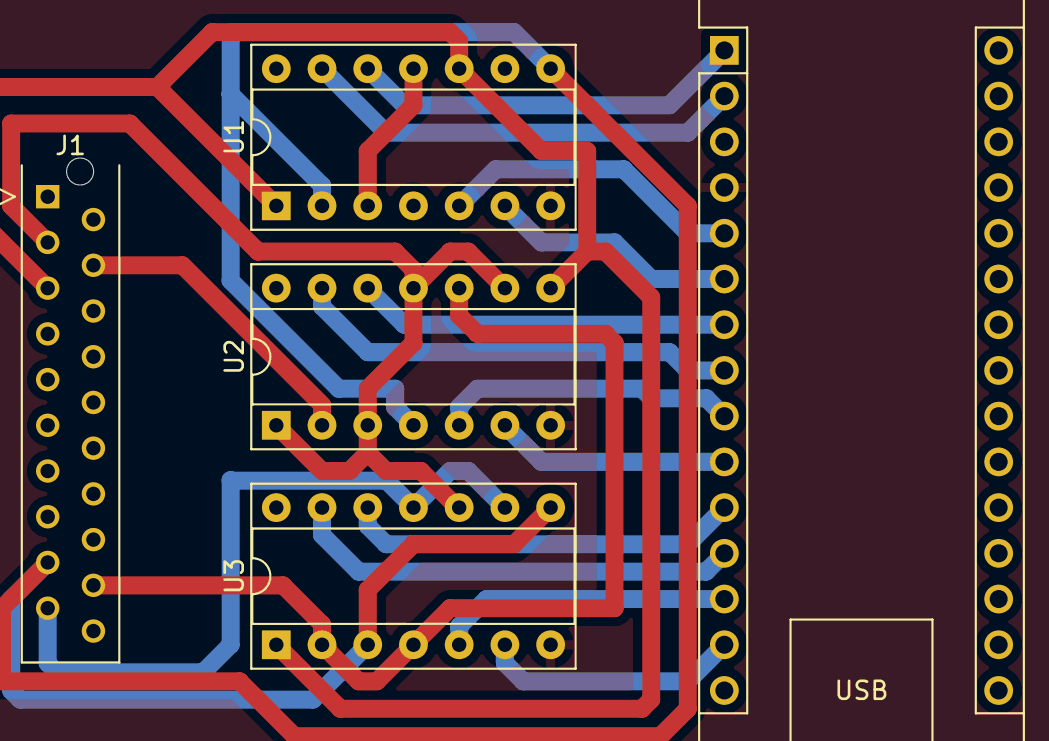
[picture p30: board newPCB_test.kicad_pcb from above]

Board: 2 copper layers, 5 parts (0 on the bottom side), 20 nets.

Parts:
A1: Arduino_Nano_v2.x; Arduino_Nano
J1: Grey_Ribbon_Main_PCB; TE_Micro-MaTch_2-215079-0_2x10_P1.27mm_Vertical
U1, U2, U3: DIP-14_W7.62mm_Socket

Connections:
3: J1.3, U2.1 (in/out_A), U2.3 (in/out_B), U2.9 (in/out_C), U2.11 (in/out_D), U3.10 (in/out_D)
4: J1.4, U1.3 (in/out_B), U1.9 (in/out_C), U1.11 (in/out_D), U2.2 (in/out_A)
5: J1.5, U1.1 (in/out_A), U1.10 (in/out_D), U2.8 (in/out_C), U3.1 (in/out_A)
17: J1.17, U1.2 (in/out_A), U1.8 (in/out_C), U2.4 (in/out_B), U3.3 (in/out_B), U3.8 (in/out_C)
18: J1.18, U2.10 (in/out_D), U3.2 (in/out_A), U3.4 (in/out_B)
19: J1.19, U1.4 (in/out_B), U3.9 (in/out_C), U3.11 (in/out_D)
+5V: A1.27 (+5V), U1.14 (Vdd), U2.14 (Vdd), U3.14 (Vdd)
A: A1.2 (D0/RX), U1.13 (Control_A)
A': A1.8 (D5), U2.13 (Control_A)
A'': A1.12 (D9), U3.13 (Control_A)
B: A1.5 (D2), U1.5 (Control_B)
B': A1.9 (D6), U2.5 (Control_B)
B'': A1.13 (D10), U3.5 (Control_B)
C: A1.6 (D3), U1.6 (Control_C)
C': A1.10 (D7), U2.6 (Control_C)
C'': A1.14 (D11), U3.6 (Control_C)
D: A1.1 (D1/TX), U1.12 (Control_D)
D': A1.7 (D4), U2.12 (Control_D)
D'': A1.11 (D8), U3.12 (Control_D)
GND: A1.4 (GND), U1.7 (Vss), U2.7 (Vss), U3.7 (Vss)

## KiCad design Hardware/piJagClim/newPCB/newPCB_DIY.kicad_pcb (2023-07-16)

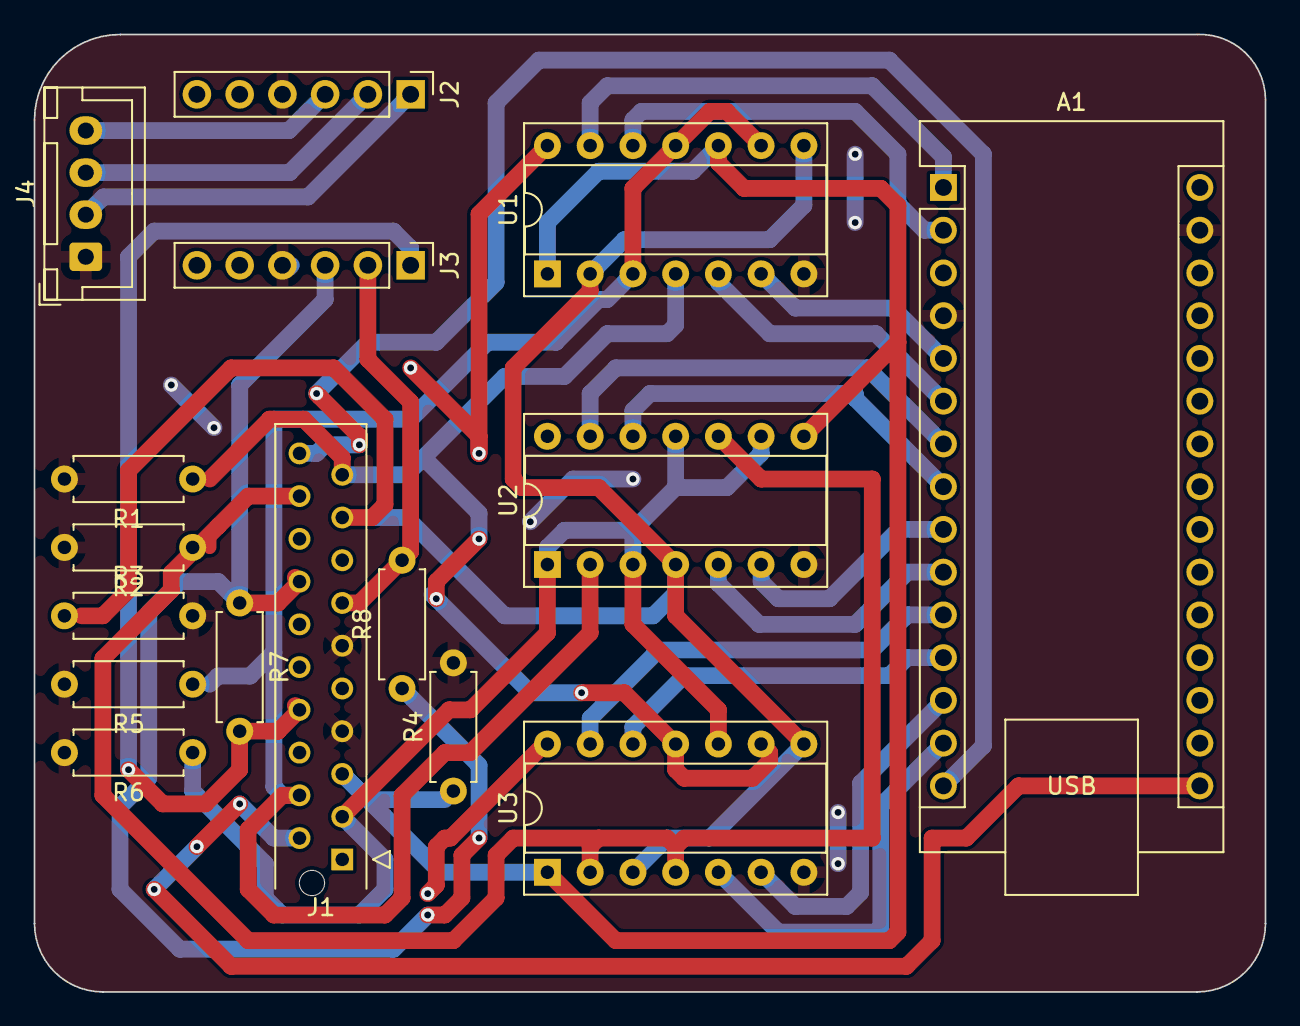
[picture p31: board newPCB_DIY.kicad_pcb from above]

Board: 2 copper layers, 73.2 x 56.9 mm, 16 parts (0 on the bottom side), 28 nets.

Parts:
A1: Arduino_Nano_v2.x; Arduino_Nano
J1: Grey_Ribbon_Main_PCB; TE_Micro-MaTch_2-215079-0_2x10_P1.27mm_Vertical
J2, J3: Conn_01x04_Pin; PinHeader_1x06_P2.54mm_Vertical
J4: Conn_01x04_Pin; JST_XH_B4B-XH-A_1x04_P2.50mm_Vertical
R1, R2, R3, R4, R5, R6: 20k; R_Axial_DIN0207_L6.3mm_D2.5mm_P7.62mm_Horizontal
R7, R8: 10k; R_Axial_DIN0207_L6.3mm_D2.5mm_P7.62mm_Horizontal
U1, U2, U3: DIP-14_W7.62mm_Socket

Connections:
2: A1.16 (D13), J1.2
3: J1.3, R6.1, U2.1 (in/out_A), U2.3 (in/out_B), U2.9 (in/out_C), U2.11 (in/out_D), U3.10 (in/out_D)
3V3: J2.3, J4.4
4: J1.4, R5.1, U1.3 (in/out_B), U1.9 (in/out_C), U1.11 (in/out_D), U2.2 (in/out_A)
5: J1.5, R4.1, U1.1 (in/out_A), U1.10 (in/out_D), U2.8 (in/out_C), U3.1 (in/out_A)
8: J1.8, J3.1, R7.2
11: A1.4 (GND), A1.29 (GND), J1.7, J1.11, J2.4, J3.4, J4.1, R1.2, R2.2, R3.2, R4.2, R5.2, R6.2, U1.7 (Vss), U2.7 (Vss), U3.7 (Vss)
13: J1.13, J3.2, R8.2
14: J1.14, J3.3, R7.1, R8.1
17: J1.17, R3.1, U1.2 (in/out_A), U1.8 (in/out_C), U2.4 (in/out_B), U3.3 (in/out_B), U3.8 (in/out_C)
18: J1.18, R2.1, U2.10 (in/out_D), U3.2 (in/out_A), U3.4 (in/out_B)
19: J1.19, R1.1, U1.4 (in/out_B), U3.9 (in/out_C), U3.11 (in/out_D)
20: A1.15 (D12), J1.20
+5V: A1.27 (+5V), U1.14 (Vdd), U2.14 (Vdd), U3.14 (Vdd)
A: A1.1 (D1/TX), U1.13 (Control_A)
A': A1.7 (D4), U2.13 (Control_A)
A'': A1.11 (D8), U3.13 (Control_A)
B: A1.6 (D3), U1.5 (Control_B)
B': A1.10 (D7), U2.5 (Control_B)
B'': A1.14 (D11), U3.5 (Control_B)
C: A1.5 (D2), U1.6 (Control_C)
C': A1.9 (D6), U2.6 (Control_C)
C'': A1.13 (D10), U3.6 (Control_C)
D: A1.2 (D0/RX), U1.12 (Control_D)
D': A1.8 (D5), U2.12 (Control_D)
D'': A1.12 (D9), U3.12 (Control_D)
SCL2: J2.1, J4.2
SDA2: J2.2, J4.3

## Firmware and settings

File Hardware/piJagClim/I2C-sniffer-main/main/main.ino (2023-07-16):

/**
 * @AUTHOR Ákos Szabó (Whitehawk Tailor) - aaszabo@gmail.com
 * 
 * This is an I2C sniffer that logs traffic on I2C BUS.
 * 
 * It is not part of the I2C BUS. It is neither a Master, nor a Slave and puts no data to the lines.
 * It just listens and logs the communication.
 * 
 * Two pins as imput are attached to SDC and SDA lines.
 * Since the I2C communications runs on 400kHz so,
 * the tool that runs this program should be fast.
 * This was tested on an ESP32 bord Heltec WiFi Lora32 v2
 * ESP32 core runs on 240MHz.
 * It means there are 600 ESP32 cycles during one I2C clock tick.
 *
 * 
 * The program uses interrupts to detect
 * the raise edge of the SCL - bit transfer 
 * the falling edge of SDA if SCL is HIGH- START
 * the raise edge of SDA if SCL id HIGH - STOP 
 * 
 * In the interrupt routines there is just a few line of code
 * that mainly sets the status and stores the incoming bits.
 * Otherwise the program gets timeout panic in interrupt handler and
 * restart the CPU.
 * 
 */


//#include <Arduino.h>

//#define I2CTEST  //use it to  run a blinking LED test on SDA and SCL pins

#define PIN_SDA A4  //BLUE
#define PIN_SCL A5  //Yellow

#define I2C_IDLE 0
//#define I2C_START 1
#define I2C_TRX 2
//#define I2C_RESP 3
//#define I2C_STOP 4

static volatile byte i2cStatus = I2C_IDLE;//Status of the I2C BUS
static uint32_t lastStartMillis = 0;//stoe the last time
static volatile byte dataBuffer[9600];//Array for storing data of the I2C communication
static volatile uint16_t bufferPoiW=0;//points to the first empty position in the dataBufer to write
static uint16_t bufferPoiR=0;//points to the position where to start read from
static volatile byte bitCount = 0;//counter of bit appeared on the BUS
static volatile uint16_t byteCount =0;//counter of bytes were writen in one communication.
static volatile byte i2cBitD =0;//Container of the actual SDA bit
static volatile byte i2cBitD2 =0;//Container of the actual SDA bit
static volatile byte i2cBitC =0;//Container of the actual SDA bit
static volatile byte i2cClk =0;//Container of the actual SCL bit
static volatile byte i2cAck =0;//Container of the last ACK value
static volatile byte i2cCase =0;//Container of the last ACK value
static volatile uint16_t falseStart = 0;//Counter of false start events
//static volatile byte respCount =0;//Auxiliary variable to help detect next byte instead of STOP
//these variables just for statistic reasons
static volatile uint16_t sclUpCnt = 0;//Auxiliary variable to count rising SCL
static volatile uint16_t sdaUpCnt = 0;//Auxiliary variable to count rising SDA
static volatile uint16_t sdaDownCnt = 0;//Auxiliary variable to count falling SDA

/////////////////////////////////
////  MAIN entry point of the program
/////////////////////////////////
void setup() 
{

	#ifdef I2CTEST
	pinMode(PIN_SCL, OUTPUT);   
    pinMode(PIN_SDA, OUTPUT);	
	#else
	//Define pins for SCL, SDA
	pinMode(PIN_SCL, INPUT_PULLUP);   
    pinMode(PIN_SDA, INPUT_PULLUP);
	//pinMode(PIN_SCL, INPUT);   
    //pinMode(PIN_SDA, INPUT);


    //reset variables
    resetI2cVariable();

    //Atach interrupt handlers to the interrupts on GPIOs
    attachInterrupt(PIN_SCL, i2cTriggerOnRaisingSCL, RISING); //trigger for reading data from SDA
	attachInterrupt(PIN_SDA, i2cTriggerOnChangeSDA, CHANGE); //for I2C START and STOP
	#endif
	Serial.begin(115200);
}//END of setup

/**
 * LOOP
 */
void loop() 
{

	#ifdef I2CTEST
	digitalWrite(PIN_SCL, HIGH);   //13 SARGA
    digitalWrite(PIN_SDA, HIGH);	//12 KEK
	delay(500);
	digitalWrite(PIN_SCL, HIGH);   //13 SARGA
    digitalWrite(PIN_SDA, LOW);	//12 KEK
	delay(500);
	#else

    //if it is in IDLE, then write out the databuffer to the serial consol
    if(i2cStatus == I2C_IDLE)
	{
		processDataBuffer();
        Serial.print("\rStart delay    ");		
        delay(5000);
        Serial.print("\rEnd delay    ");
		delay(500);
	}

	#endif

}//END of loop


////////////////////////////
//// Interrupt handlers
/////////////////////////////

/**
 * Rising SCL makes reading the SDA
 * 
 */
void i2cTriggerOnRaisingSCL() 
{
  sclUpCnt++;
  
  //is it a false trigger?
  if(i2cStatus==I2C_IDLE)
  {
    falseStart++;
    //return;//this is not clear why do we have so many false START
  }


  //get the value from SDA
  i2cBitC =  digitalRead(PIN_SDA);

  //decide wherewe are and what to do with incoming data
  i2cCase = 0;//normal case

  if(bitCount==8)//ACK case
    i2cCase = 1;

  if(bitCount==7 && byteCount==0 )// R/W if the first address byte
    i2cCase = 2;

  bitCount++;

  switch (i2cCase)
  {
    case 0: //normal case
      dataBuffer[bufferPoiW++] = '0' + i2cBitC;//48
    break;//end of case 0 general
    case 1://ACK
      if(i2cBitC)//1 NACK SDA HIGH
        {
          dataBuffer[bufferPoiW++] = '-';//45
        }
        else//0 ACK SDA LOW
        {
          dataBuffer[bufferPoiW++] = '+';//43
        } 
      byteCount++;
      bitCount=0;
    break;//end of case 1 ACK
    case 2:
      if(i2cBitC)
      {
        dataBuffer[bufferPoiW++] = 'R';//82
      }
      else
      {
        dataBuffer[bufferPoiW++] = 'W';//87
      }
    break;//end of case 2 R/W

  }//end of switch

}//END of i2cTriggerOnRaisingSCL() 

/**
 * This is for recognizing I2C START and STOP
 * This is called when the SDA line is changing
 * It is decided inside the function wheather it is a rising or falling change.
 * If SCL is on High then the falling change is a START and the rising is a STOP.
 * If SCL is LOW, then this is the action to set a data bit, so nothing to do.
 */
void i2cTriggerOnChangeSDA()
{
  //make sure that the SDA is in stable state
  do
  {
    i2cBitD =  digitalRead(PIN_SDA);
    i2cBitD2 =  digitalRead(PIN_SDA);
  } while (i2cBitD!=i2cBitD2);

  //i2cBitD =  digitalRead(PIN_SDA);

  if(i2cBitD)//RISING if SDA is HIGH (1)
  {
    
    i2cClk = digitalRead(PIN_SCL);
    if(i2cStatus=!I2C_IDLE && i2cClk==1)//If SCL still HIGH then it is a STOP sign
    {     
      //i2cStatus = I2C_STOP;
      i2cStatus = I2C_IDLE;
      bitCount = 0;
      byteCount = 0;
      bufferPoiW--;
      dataBuffer[bufferPoiW++] = 's';//115
      dataBuffer[bufferPoiW++] = '\n'; //10
    }
    sdaUpCnt++;
  }
  else //FALLING if SDA is LOW
  {
    
    i2cClk = digitalRead(PIN_SCL);
    if(i2cStatus==I2C_IDLE && i2cClk)//If SCL still HIGH than this is a START
    {
      i2cStatus = I2C_TRX;
      //lastStartMillis = millis();//takes too long in an interrupt handler and caused timeout panic and CPU restart
      bitCount = 0;
      byteCount =0;
      dataBuffer[bufferPoiW++] = 'S';//83 STOP
      //i2cStatus = START;    
    }
    sdaDownCnt++;
  }
}//END of i2cTriggerOnChangeSDA()


////////////////////////////////
//// Functions
////////////////////////////////

/**
 * Reset all important variable
 */
void resetI2cVariable()
{
  i2cStatus = I2C_IDLE;
  bufferPoiW=0;
  bufferPoiR=0;
  bitCount =0;
  falseStart = 0;
}//END of resetI2cVariable()


/**
* @DESC Write out the buffer to the serial console
*
*/
void processDataBuffer()
{
  if(bufferPoiW == bufferPoiR)//There is nothing to say
    return;

  uint16_t pw = bufferPoiW;
  //print out falseStart
  //Serial.printf("\nSCL up: %d SDA up: %d SDA down: %d false start: %d\n", sclUpCnt, sdaUpCnt, sdaDownCnt, falseStart);
  //print out the content of the buffer 
  for(int i=bufferPoiR; i< pw; i++)
  {
    Serial.write(dataBuffer[i]);
    bufferPoiR++;   
  }
  
  //if there is no I2C action in progress and there wasn't during the Serial.print then buffer was printed out completly and can be reset.
  if(i2cStatus == I2C_IDLE && pw==bufferPoiW)
  {
    bufferPoiW =0;
    bufferPoiR =0;
  } 
}//END of processDataBuffer()

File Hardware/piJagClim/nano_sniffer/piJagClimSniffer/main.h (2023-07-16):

#ifndef _main_h_
#define _main_h_
#include <avr\interrupt.h>
#include <avr\io.h>
#include <stddef.h>
#include "mydefs.h"


// #define SNIFFER_MODE
// #define TEST_MODE
#define PARSER_MODE


#define	LINEFEED	"\r\n"


//#define	STX_DDR		SBIT( DDRB, 1 )		// must be OC1A !

#define	SDA		SBIT( PORTB, 0 )
#define	SDA_DDR		SBIT( DDRB, 0 )
#define	SDA_PIN		SBIT( PINB, 0 )

#define	UTX		SBIT( PORTB, 1 )
#define	UTX_DDR		SBIT( DDRB, 1 )
#define	UTX_PIN		SBIT( PINB, 1 )

#define	SCL		SBIT( PORTB, 2 )
#define SCL_DDR		SBIT( DDRB, 2 )
#define	SCL_PIN		SBIT( PINB, 2 )

#define	RAW		SBIT( PORTB, 3 )
#define RAW_DDR		SBIT( DDRB, 3 )
#define	RAW_PIN		SBIT( PINB, 3 )

#define	DLA		SBIT( PORTB, 4 )
#define DLA_DDR		SBIT( DDRB, 4 )
#define	DLA_PIN		SBIT( PINB, 4 )

#endif

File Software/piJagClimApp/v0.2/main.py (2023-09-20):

import os
import sys
from PyQt5.QtWidgets import QMainWindow, QApplication

import piJagClimv02_ui
from utils.arduinoReader import SerialReaderThread
from utils.arduinoWriter import SerialWriterThread
from utils.ArduinoSimul import arduinoSimul
from utils.utils import temp, fan, air, temp2tempDial
import serial
import serial.tools.list_ports
import time


class piJagClimateGUI(QMainWindow, piJagClimv02_ui.Ui_MainWindow):
    def __init__(self, dir_folder):
        super().__init__()

        self.setupUi(self) #, dir_folder)

        # Initialize and connect to serial or simulate
        """
        self.comPorts = serial.tools.list_ports.comports()
        self.nameList = list(port.device for port in self.comPorts)
        print(self.nameList)
        if len(self.nameList) > 0:
        """
        # piJag.rules redirect arduino by id to port /dev/piJagClim
        try:
            self.arduino = serial.Serial(port='/dev/piJagClim', baudrate=115200, timeout=.1)
            self.simul = False
        except:
            self.arduino = arduinoSimul()
            self.simul = True

        # Serial threads

        self.serialReaderThread = SerialReaderThread(serial=self.arduino)
        self.serialReaderThread.receivedPacketSignal.connect(self.serialPacketReceiverCallback)
        self.serialWriterThread = SerialWriterThread(serial=self.arduino)
        self.serialReaderThread.start()
        self.serialWriterThread.start()

        # Label default values
        self._temp = ""
        self._fan = ""
        self._air = ""

        self._ac = False
        self._rear = False
        self._color = {'r': 0, 'g': 0, 'b': 0, 'a': 255}

        # Dial default values
        self._tempDial = 15
        self._fanDial = 5

        # "on" default value
        self._on = True

        # OnOff
        self.onoffButton.clicked.connect(self.onoff)

        # Temperature
        self.tempDial.sliderReleased.connect(self.changeTemp)
        self.tempDial.valueChanged.connect(self.changeTempColor)
        self.tempPlusButton.clicked.connect(self.plusTemp)
        self.tempMinusButton.clicked.connect(self.minusTemp)
        self.tempACButton.clicked.connect(self.tempAC)
        self.tempDial.setEnabled(False)
        self.tempPlusButton.setEnabled(False)
        self.tempMinusButton.setEnabled(False)
        self.tempACButton.setEnabled(False)

        # Fan
        self.fanDial.sliderReleased.connect(self.changeFan)
        self.fanDial.valueChanged.connect(self.changeFanColor)
        self.fanMinusButton.clicked.connect(self.minusFan)
        self.fanPlusButton.clicked.connect(self.plusFan)
        self.fanAutoButton.clicked.connect(self.autoFan)
        self.fanDial.setEnabled(False)
        self.fanMinusButton.setEnabled(False)
        self.fanPlusButton.setEnabled(False)
        self.fanAutoButton.setEnabled(False)

        # Controls
        self.airFaceButton.clicked.connect(self.airFace)
        self.airFeetButton.clicked.connect(self.airFeet)
        self.airFeetFaceButton.clicked.connect(self.airFeetFace)
        self.airFrontDefrostButton.clicked.connect(self.airFront)
        self.airFeetFrontDefrostButton.clicked.connect(self.airFeetFront)
        self.airRearDefrostButton.clicked.connect(self.airRear)
        self.airRecyclingButton.clicked.connect(self.airRecycle)
        self.airFaceButton.setEnabled(False)
        self.airFeetButton.setEnabled(False)
        self.airFeetFaceButton.setEnabled(False)
        self.airFrontDefrostButton.setEnabled(False)
        self.airFeetFrontDefrostButton.setEnabled(False)
        self.airRearDefrostButton.setEnabled(False)
        self.airRecyclingButton.setEnabled(False)

        self.list_air_buttons = [self.airFeetFaceButton,
                                 self.airFaceButton,
                                 self.airFeetButton,
                                 self.airFrontDefrostButton,
                                 self.airFeetFrontDefrostButton
                                 ]

        time.sleep(1.5) # Wait for threads to initialize
        self.write(b'\x10') # Ask for values

    def serialPacketReceiverCallback(self, packet):
        if packet[13] == '00':
            self._temp = ''
            self._fan = ''
            self._air = ''
            self._color = {'r': 0, 'g': 0, 'b': 0, 'a': 255}
            #self.onoffButton.setText('On')
            self._on = False
        else:
            self._temp = temp(packet)
            self._fan = fan(packet)
            self._air = air(packet)
            self._color = self.tempDial.getColor()
            self.onoffButton.select(self._color)
            #self.onoffButton.setText('Off')
            self._on = True
        self.tempDial.setVal(self._temp)
        self.updateButtonsBackground()

        self._tempDial = temp2tempDial(self._temp)
        self.tempDial.setValue(self._tempDial)
        self.tempDial.changeColor(self._tempDial)

        self.fanDial.setVal(self._fan)
        if self._fan != 'Auto':
            try:
                self.fanAutoButton.deselect()
                self._fanDial = int(self._fan)
                self.fanDial.setValue(self._fanDial)
            except:
                self.fanDial.setValue(6)
            self.fanDial.changeColor(self._fanDial)
        else:
            self.fanAutoButton.select(color=self.fanDial.getColor())
            self.fanDial.animateCursor()

        if self._tempDial < 10 and self._ac:
            self.tempACButton.select(self._color)
        if self._tempDial > 10 or self._air == 'Front':
            self._ac = False
            self.tempACButton.deselect()

    def write(self, x):
        self.serialWriterThread.write(x)

    def onoff(self):
        self.write(b'\x01')

        if self._on:
            # Temperature
            self.tempDial.setEnabled(False)
            self.tempPlusButton.setEnabled(False)
            self.tempMinusButton.setEnabled(False)
            self.tempACButton.setEnabled(False)

            # Fan
            self.fanDial.setEnabled(False)
            self.fanMinusButton.setEnabled(False)
            self.fanPlusButton.setEnabled(False)
            self.fanAutoButton.setEnabled(False)

            # Controls
            self.airFaceButton.setEnabled(False)
            self.airFeetButton.setEnabled(False)
            self.airFeetFaceButton.setEnabled(False)
            self.airFrontDefrostButton.setEnabled(False)
            self.airFeetFrontDefrostButton.setEnabled(False)
            self.airRearDefrostButton.setEnabled(False)
            self.airRecyclingButton.setEnabled(False)

            self.onoffButton.deselect()

        else:
            # Temperature
            self.tempDial.setEnabled(True)
            self.tempPlusButton.setEnabled(True)
            self.tempMinusButton.setEnabled(True)
            self.tempACButton.setEnabled(True)
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

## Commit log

2023-07-16 first global commit
    [Ribbon_pinout.kicad_sch, canDrive_comp_pcb_lib.PcbLib, canDrive_comp_sch_lib.SchLib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]
2023-09-01 arduino test new PCB
2023-09-03 I2C & control + - of climate module test
2023-09-03 new pcb piJagClim version
    [newPCBv0.2-B_Cu.gbr, newPCBv0.2-B_Mask.gbr, newPCBv0.2-B_Paste.gbr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]
2023-09-03 serial com python-arduino test
2023-09-04 Reading temperature
2023-09-05 All readings and controls except Fan
2023-09-05 rotary encoder
2023-09-06 Threads for receiving and sending through serial
2023-09-06 Replaced PCB v0.2 and Added pyQT App
2023-09-07 Global window layout & Knobs design & On Off Button
2023-09-08 Control buttons design
2023-09-16 USB port fixed and rules file
    [main.py]
